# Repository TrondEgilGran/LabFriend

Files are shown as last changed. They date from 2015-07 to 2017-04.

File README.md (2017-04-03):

# LabFriend
Open Source USB Oscilloscope

Complete Open-Source USB basted oscillosope and measurement system.
2 Analog 200Msps channels 8 bit.
8 Digital 200Msps channels.
8 Digital Outputs
2 97KHz Audio frequency channel IO 24 bit.
3 High accuracy 16 bit DC inputs
1 8 bit 3Msps (low accuracy DAC).
1 DC output 0-5V max 20mA.

C-library for accessing HW. 
QT GUI Application.

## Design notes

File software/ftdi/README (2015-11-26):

To write SPI EEPROM on the ftdi chip using the programming tool from libftdi:
erase:
ftdi_eeprom --erase-eeprom  labfriend-usb.conf
flash:
ftdi_eeprom --flash-eeprom  labfriend-usb.conf

Make sure normal users have access to the FTDI device put the following
file:
53-teg-labfriend-usb.rules
to
/etc/udev/rules.d/
(this is for most modern Linux distributions in 2015 running udev)

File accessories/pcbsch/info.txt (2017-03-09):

pcb and shematics fro accesssories to then labfriend scope

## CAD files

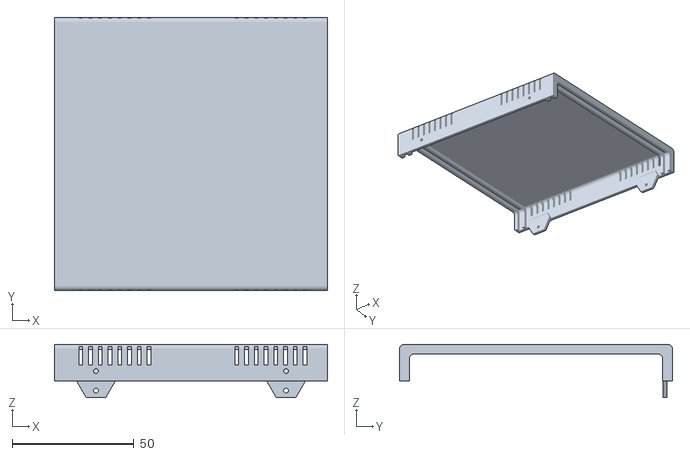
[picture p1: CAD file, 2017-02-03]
box/top.stl
112.0 x 112.0 x 21.9

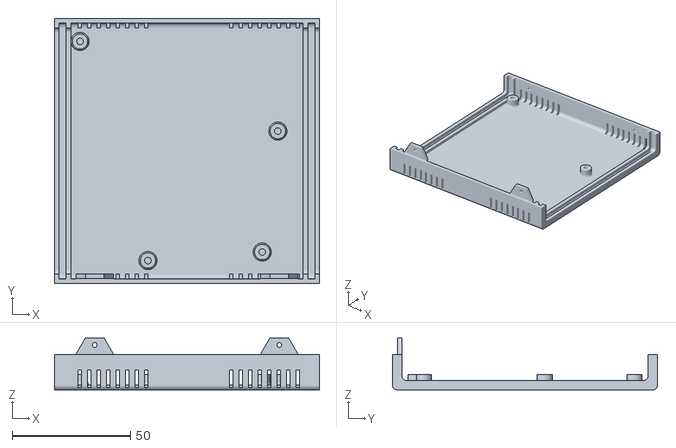
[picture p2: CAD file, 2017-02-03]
box/botom.stl
112.0 x 112.0 x 21.9

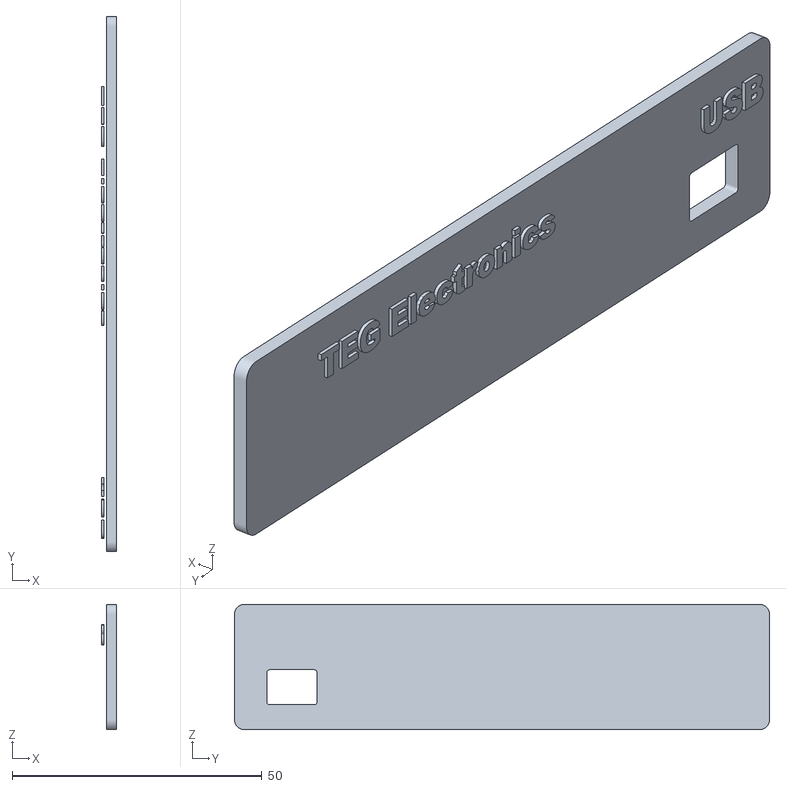
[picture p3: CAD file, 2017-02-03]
box/backpanel.stl
3.00 x 107.1 x 25.1

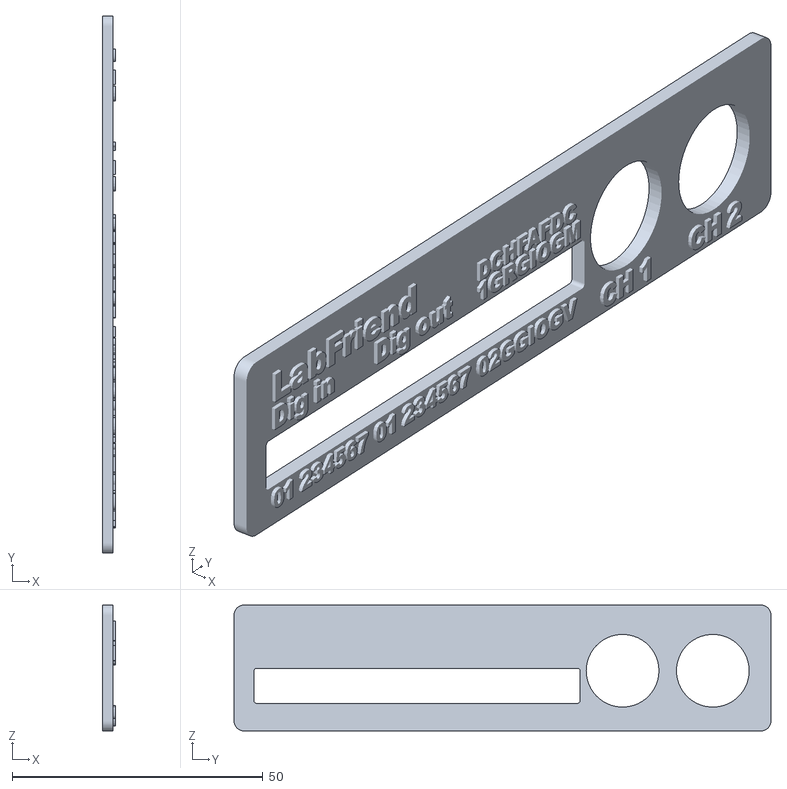
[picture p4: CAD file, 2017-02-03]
box/frontpanel.stl
2.50 x 107.1 x 25.1

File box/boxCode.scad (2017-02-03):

/*//////////////////////////////////////////////////////////////////
              -    FB Aka Heartman/Hearty 2016     -                   
              -   http://heartygfx.blogspot.com    -                  
              -       OpenScad Parametric Box      -                     
              -         CC BY-NC 3.0 License       -                      
////////////////////////////////////////////////////////////////////                                                                                                             
12/02/2016 - Fixed minor bug 
28/02/2016 - Added holes ventilation option                    
09/03/2016 - Added PCB feet support, fixed the shell artefact on export mode. 

*/////////////////////////// - Info - //////////////////////////////

// All coordinates are starting as integrated circuit pins.
// From the top view :

//   CoordD           <---       CoordC
//                                 ^
//                                 ^
//                                 ^
//   CoordA           --->       CoordB


////////////////////////////////////////////////////////////////////


////////// - Paramètres de la boite - Box parameters - /////////////

/* [Box dimensions] */
// - Longueur - Length  
  Length        = 112;       
// - Largeur - Width
  Width         = 112;                     
// - Hauteur - Height  
  Height        = 30;  
// - Epaisseur - Wall thickness  
  Thick         = 2;//[2:5]  
  
/* [Box options] */
// - Diamètre Coin arrondi - Filet diameter  
  Filet         = 2;//[0.1:12] 
// - lissage de l'arrondi - Filet smoothness  
  Resolution    = 50;//[1:100] 
// - Tolérance - Tolerance (Panel/rails gap)
  m             = 0.9;
// Pieds PCB - PCB feet (x4) 
  PCBFeet       = 0;// [0:No, 1:Yes]
// - Decorations to ventilation holes
  Vent          = 1;// [0:No, 1:Yes]
// - Decoration-Holes width (in mm)
  Vent_width    = 1.5;   


  
/* [PCB_Feet] */
//All dimensions are from the center foot axis

// - Coin bas gauche - Low left corner X position
PCBPosX         = 0;
// - Coin bas gauche - Low left corner Y position
PCBPosY         = 4;
// - Longueur PCB - PCB Length
PCBLength       = 100;
// - Largeur PCB - PCB Width
PCBWidth        = 100;
// - Heuteur pied - Feet height
FootHeight      = 7;
// - Diamètre pied - Foot diameter
FootDia         = 6.5;
// - Diamètre trou - Hole diameter
FootHole        = 2.8;  

Foot1PosX        = 33.5;
Foot1PosY        = 3.7;
Foot2PosX        = 4.8;
Foot2PosY        = 96.3;
Foot3PosX        = 88.4;
Foot3PosY        = 58.4;
Foot4PosX        = 81.8;
Foot4PosY        = 7.3;
  

/* [STL element to export] */
//Coque haut - Top shell
TShell          = 0;// [0:No, 1:Yes]
//Coque bas- Bottom shell
BShell          = 0;// [0:No, 1:Yes]
//Panneau avant - Front panel
FPanL           = 0;// [0:No, 1:Yes]
//Panneau arrière - Back panel  
BPanL           = 1;// [0:No, 1:Yes]


  
/* [Hidden] */
// - Couleur coque - Shell color  
Couleur1        = "Orange";       
// - Couleur panneaux - Panels color    
Couleur2        = "OrangeRed";    
// Thick X 2 - making decorations thicker if it is a vent to make sure they go through shell
Dec_Thick       = Vent ? Thick*2 : Thick; 
// - Depth decoration
Dec_size        = Vent ? Thick*2 : 0.8;





/////////// - Boitier générique bord arrondis - Generic rounded box - //////////

module RoundBox($a=Length, $b=Width, $c=Height){// Cube bords arrondis
                    $fn=Resolution;            
                    translate([0,Filet,Filet]){  
                    minkowski (){                                              
                        cube ([$a-(Length/2),$b-(2*Filet),$c-(2*Filet)], center = false);
                        rotate([0,90,0]){    
                        cylinder(r=Filet,h=Length/2, center = false);
                            } 
                        }
                    }
                }// End of RoundBox Module

      
////////////////////////////////// - Module Coque/Shell - //////////////////////////////////         

module Coque(){//Coque - Shell  
    Thick = Thick*2;  
    difference(){    
        difference(){//sides decoration
            union(){    
                     difference() {//soustraction de la forme centrale - Substraction Fileted box
                      
                        difference(){//soustraction cube median - Median cube slicer
                            union() {//union               
                            difference(){//Coque    
                                RoundBox();
                                translate([Thick/2,Thick/2,Thick/2]){     
                                        RoundBox($a=Length-Thick, $b=Width-Thick, $c=Height-Thick);
                                        }
                                        }//Fin diff Coque                            
                                difference(){//largeur Rails        
                                     translate([Thick+m,Thick/2,Thick/2]){// Rails
                                          RoundBox($a=Length-((2*Thick)+(2*m)), $b=Width-Thick, $c=Height-(Thick*2));
                                                          }//fin Rails
                                     translate([((Thick+m/2)*1.55),Thick/2,Thick/2+0.1]){ // +0.1 added to avoid the artefact
                                          RoundBox($a=Length-((Thick*3)+2*m), $b=Width-Thick, $c=Height-Thick);
                                                    }           
                                                }//Fin largeur Rails
                                    }//Fin union                                   
                               translate([-Thick,-Thick,Height/2]){// Cube à soustraire
                                    cube ([Length+100, Width+100, Height], center=false);
                                            }                                            
                                      }//fin soustraction cube median - End Median cube slicer
                               translate([-Thick/2,Thick,Thick]){// Forme de soustraction centrale 
                                    RoundBox($a=Length+Thick, $b=Width-Thick*2, $c=Height-Thick);       
                                    }                          
                                }                                          


                difference(){// wall fixation box legs
                    union(){
                        translate([3*Thick +5,Thick,Height/2]){
                            rotate([90,0,0]){
                                    $fn=6;
                                    cylinder(d=16,Thick/2);
                                    }   
                            }
                            
                       translate([Length-((3*Thick)+5),Thick,Height/2]){
                            rotate([90,0,0]){
                                    $fn=6;
                                    cylinder(d=16,Thick/2);
                                    }   
                            }

                        }
                            translate([4,Thick+Filet,Height/2-57]){   
                             rotate([45,0,0]){
                                   cube([Length,40,40]);    
                                  }
                           }
                           translate([0,-(Thick*1.46),Height/2]){
                                cube([Length,Thick*2,10]);
                           }
                    } //Fin fixation box legs
            }

        union(){// outbox sides decorations
            
            for(i=[0:Thick:Length/4]){

                // Ventilation holes part code submitted by Ettie - Thanks ;) 
                    translate([10+i,-Dec_Thick+Dec_size,1]){
                    cube([Vent_width,Dec_Thick,Height/4]);
                    }
                    translate([(Length-10) - i,-Dec_Thick+Dec_size,1]){
                    cube([Vent_width,Dec_Thick,Height/4]);
                    }
                    translate([(Length-10) - i,Width-Dec_size,1]){
                    cube([Vent_width,Dec_Thick,Height/4]);
                    }
                    translate([10+i,Width-Dec_size,1]){
                    cube([Vent_width,Dec_Thick,Height/4]);
                    }
  
                
                    }// fin de for
               // }
                }//fin union decoration
            }//fin difference decoration
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

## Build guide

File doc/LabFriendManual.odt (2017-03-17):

LabFriend Manual

# Connectors

Hhh

'

Pin Number | Function
1 | CMPMEAS, Component measurement pin (caps inductors, resistors)
2 | EXVO, Voltage output, max 50mA 5V (adjustable)
3 | GND
4 | GND
5 | AOUTR, High Resolution AF channel 1 output
6 | AOUTL, High Resolution AF channel 2 output
7 | AINR, High Resolution AF channel 1 input
8 | AINL, High Resolution AF channel 2 input
9 | GND
10 | GND
11 | HFDAC, 3MHz DAC out, 8 bit 0 - 5V
12 | GND
13 | GND
14 | DCMEAS3, DC measurement 0-5V 16bit +gain
15 | DCMEAS1, DC measurement 0-5V 16bit +gain (can be used with channel 2 in diff m)
15 | DCMEAS2, DC measurement 0-5V 16bit +gain

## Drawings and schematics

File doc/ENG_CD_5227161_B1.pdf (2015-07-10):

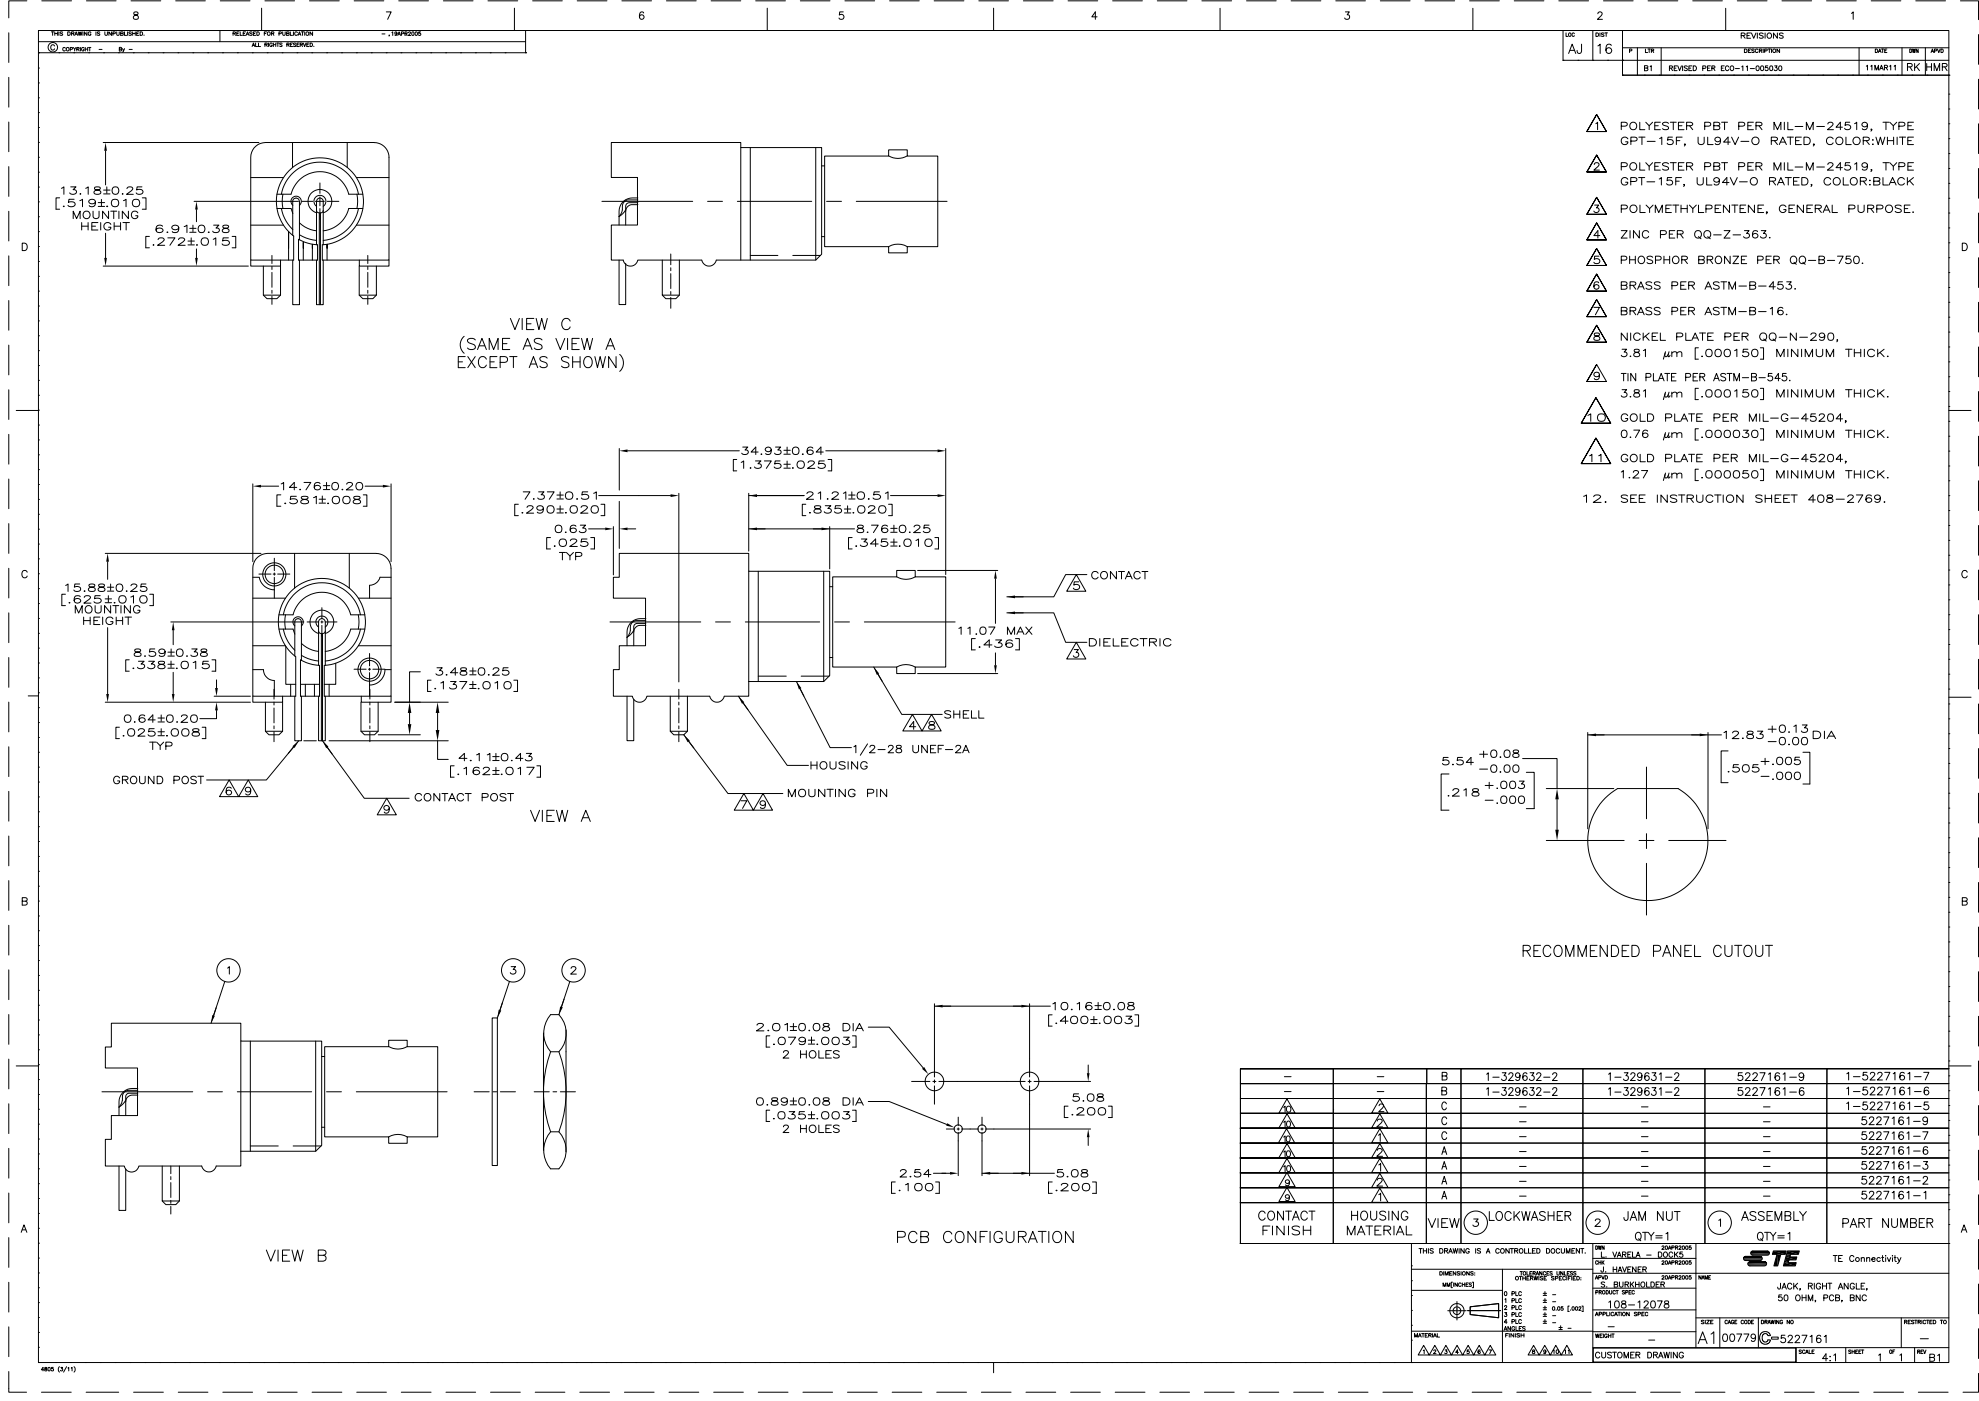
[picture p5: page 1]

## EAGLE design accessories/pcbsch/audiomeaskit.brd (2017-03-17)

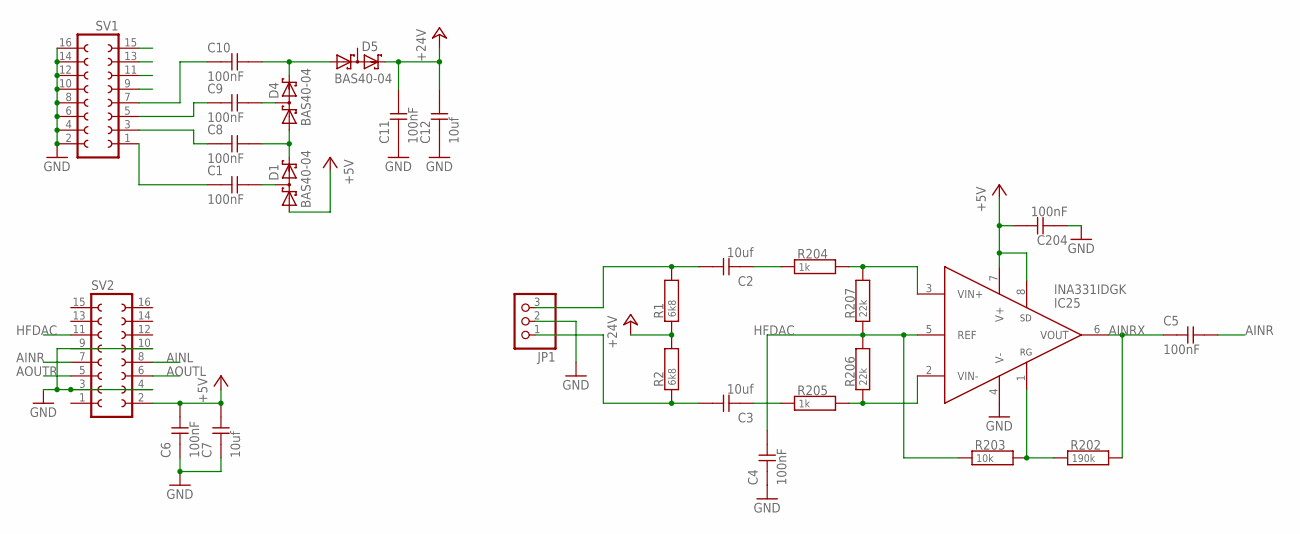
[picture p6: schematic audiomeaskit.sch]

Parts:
C1, C4, C5, C6, C8, C9, C10, C11: 100nF; 0603
C2, C3, C7, C12: 10uf; 0805
C204: 100nF; 0402
D1, D4, D5: BAS40-04; SOT23
IC25: INA331IDGK; MSOP08
JP1: PINHD-1X3; 1X03
R1, R2: 6k8; 0603
R202: 190k; 0603
R203: 10k; 0603
R204, R205: 1k; 0603
R206, R207: 22k; 0603
SV1, SV2: FE08-2

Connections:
+5V: C6.2, C7.2, C204.2, D1.1 (A1), IC25.7 (V+), IC25.8 (SD), SV2.2
+24V: C11.2, C12.2, D5.2 (C2), R1.1, R2.2
AINL: SV2.8
AINR: C5.2, SV2.7
AINRX: C5.1, IC25.6 (VOUT), R202.2
AOUTL: SV2.6
AOUTR: SV2.5
GND: C4.1, C6.1, C7.1, C11.1, C12.1, C204.1, IC25.4 (V-), JP1.2, SV1.2, SV1.4, SV1.6, SV1.8, SV1.10, SV1.12, SV1.14, SV1.16, SV2.3, SV2.4, SV2.9, SV2.10
HFDAC: C4.2, IC25.5 (REF), R203.1, R206.2, R207.1, SV2.11
unnamed: C8.1, SV1.3
unnamed: C3.2, JP1.1, R2.1
unnamed: C2.2, JP1.3, R1.2
unnamed: C1.1, SV1.1
unnamed: C1.2, D1.3 (C1A2)
unnamed: C10.1, SV1.7
unnamed: C8.2, D1.2 (C2), D4.1 (A1)
unnamed: C9.1, SV1.5
unnamed: C9.2, D4.3 (C1A2)
unnamed: C10.2, D4.2 (C2), D5.1 (A1)
unnamed: IC25.1 (RG), R202.1, R203.2
unnamed: IC25.3 (VIN+), R204.2, R207.2
unnamed: IC25.2 (VIN-), R205.2, R206.1
unnamed: C2.1, R204.1
unnamed: C3.1, R205.1
S1: SV1.9
S2: SV1.11
S3: SV1.13
S4: SV1.15

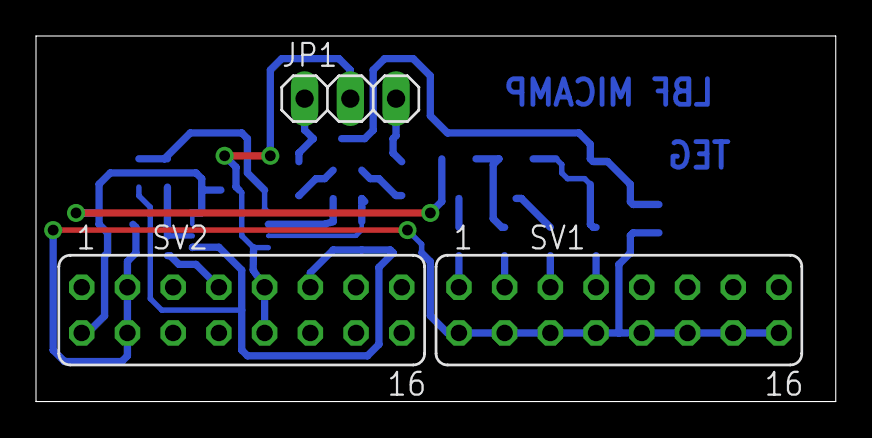
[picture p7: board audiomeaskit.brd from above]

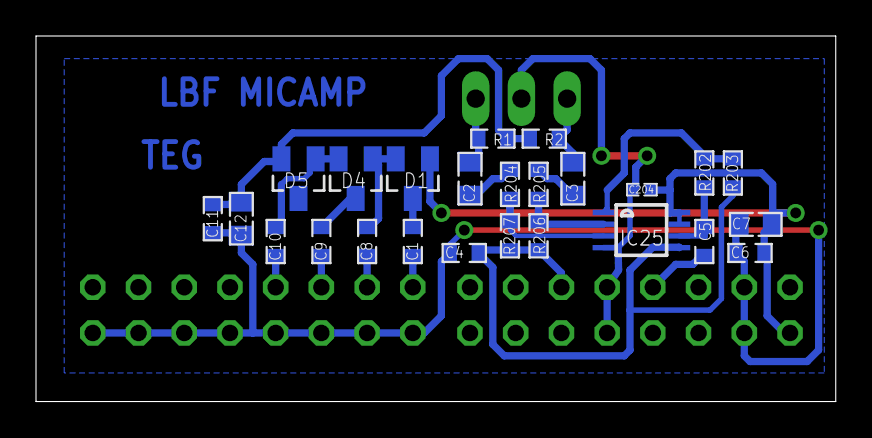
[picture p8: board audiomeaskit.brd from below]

Board: 2 copper layers, 44.4 x 20.3 mm, 28 parts (25 on the bottom side), 21 nets.

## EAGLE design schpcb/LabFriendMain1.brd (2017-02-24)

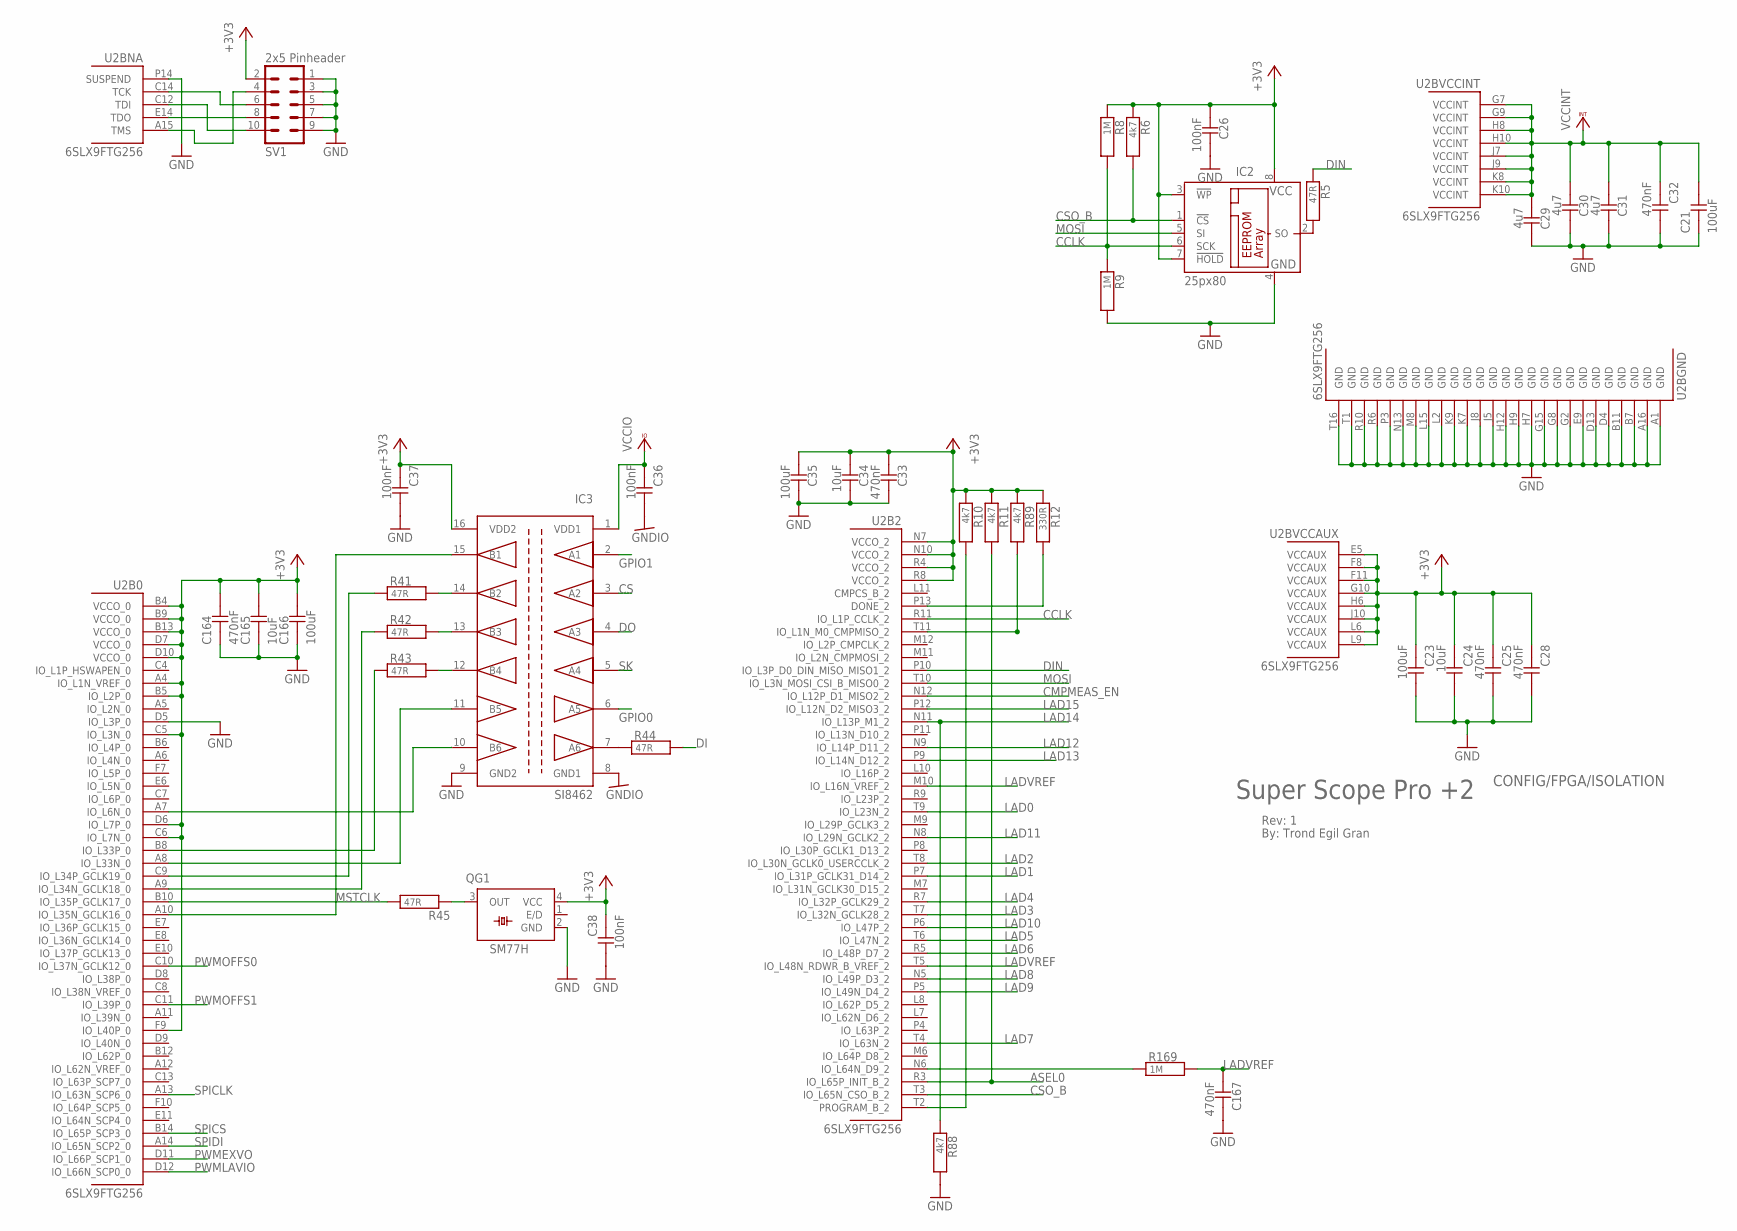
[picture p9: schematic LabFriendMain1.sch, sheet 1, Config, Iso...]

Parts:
C21, C23, C35, C166: 100uF; 1206
C24, C34, C165: 10uF; 0603
C25, C28, C32, C33, C164, C167: 470nF; 0402
C26, C36, C37, C38: 100nF; 0402
C29, C30, C31: 4u7; 0603
IC2: 25px80; SO-08
IC3: SI8462; SO16
QG1: SM77H
R5, R41, R42, R43, R44, R45: 47R; 0402
R6, R10, R11, R88, R89: 4k7; 0402
R8, R9, R169: 1M; 0402
R12: 330R; 0402
SV1: 2x5 Pinheader; ML10
U2: 6SLX9FTG256; FT256

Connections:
+3V3: C23.1, C24.1, C25.1, C26.1, C28.1, C33.1, C34.1, C35.1, C37.1, C38.1, C164.2, C165.2, C166.2, IC2.3 (!WP), IC2.7 (!HOLD), IC2.8 (VCC), IC3.16 (VDD2), QG1.4 (VCC), R6.1, R8.1, R10.1, R11.1, R12.1, R89.1, SV1.2, U2.A4 (IO_L1N_VREF_0), U2.B4 (VCCO_0), U2.B5 (IO_L2P_0), U2.B9 (VCCO_0), U2.B13 (VCCO_0), U2.C5 (IO_L3N_0), U2.C6 (IO_L7N_0), U2.D6 (IO_L7P_0), U2.D7 (VCCO_0), U2.D10 (VCCO_0), U2.E5 (VCCAUX), U2.F8 (VCCAUX), U2.F9 (IO_L40P_0), U2.F11 (VCCAUX), U2.G10 (VCCAUX), U2.H6 (VCCAUX), U2.J10 (VCCAUX), U2.L6 (VCCAUX), U2.L9 (VCCAUX), U2.N7 (VCCO_2), U2.N10 (VCCO_2), U2.R4 (VCCO_2), U2.R8 (VCCO_2); also elsewhere on the board
ASEL0: R11.2, U2.R3 (IO_L65P_INIT_B_2)
CCLK: IC2.6 (SCK), R8.2, R9.1, U2.R11 (IO_L1P_CCLK_2)
CMPMEAS_EN: U2.N12 (IO_L12P_D1_MISO2_2); also elsewhere on the board
CS: IC3.3 (A2); also elsewhere on the board
CSO_B: IC2.1 (!CS), R6.2, U2.T3 (IO_L65N_CSO_B_2)
DI: R44.2; also elsewhere on the board
DIN: R5.1, U2.P10 (IO_L3P_D0_DIN_MISO_MISO1_2)
DO: IC3.4 (A3); also elsewhere on the board
GND: C21.1, C23.2, C24.2, C25.2, C26.2, C28.2, C29.2, C30.2, C31.2, C32.2, C33.2, C34.2, C35.2, C37.2, C38.2, C164.1, C165.1, C166.1, C167.2, IC2.4 (GND), IC3.9 (GND2), QG1.2 (GND), R9.2, R88.2, SV1.1, SV1.3, SV1.5, SV1.7, SV1.9, U2.A1 (GND), U2.A16 (GND), U2.B7 (GND), U2.B11 (GND), U2.D4 (GND), U2.D5 (IO_L3P_0), U2.D13 (GND), U2.E9 (GND), U2.G2 (GND), U2.G8 (GND), U2.G15 (GND), U2.H7 (GND), U2.H9 (GND), U2.H12 (GND), U2.J5 (GND), U2.J8 (GND), U2.K7 (GND), U2.K9 (GND), U2.L2 (GND), U2.L15 (GND), U2.M8 (GND), U2.N13 (GND), U2.P3 (GND), U2.P14 (SUSPEND), U2.R6 (GND), U2.R10 (GND), U2.T1 (GND), U2.T16 (GND); also elsewhere on the board
GNDIO: C36.2, IC3.8 (GND1); also elsewhere on the board
GPIO0: IC3.6 (A5); also elsewhere on the board
GPIO1: IC3.2 (A1); also elsewhere on the board
LAD0: U2.T9 (IO_L23N_2); also elsewhere on the board
LAD1: U2.P7 (IO_L31P_GCLK31_D14_2); also elsewhere on the board
LAD2: U2.T8 (IO_L30N_GCLK0_USERCCLK_2); also elsewhere on the board
LAD3: U2.T7 (IO_L32N_GCLK28_2); also elsewhere on the board
LAD4: U2.R7 (IO_L32P_GCLK29_2); also elsewhere on the board
LAD5: U2.T6 (IO_L47N_2); also elsewhere on the board
LAD6: U2.R5 (IO_L48P_D7_2); also elsewhere on the board
LAD7: U2.T4 (IO_L63N_2); also elsewhere on the board
LAD8: U2.N5 (IO_L49P_D3_2); also elsewhere on the board
LAD9: U2.P5 (IO_L49N_D4_2); also elsewhere on the board
LAD10: U2.P6 (IO_L47P_2); also elsewhere on the board
LAD11: U2.N8 (IO_L29N_GCLK2_2); also elsewhere on the board
LAD12: U2.N9 (IO_L14P_D11_2); also elsewhere on the board
LAD13: U2.P9 (IO_L14N_D12_2); also elsewhere on the board
LAD14: R88.1, U2.N11 (IO_L13P_M1_2); also elsewhere on the board
LAD15: U2.P12 (IO_L12N_D2_MISO3_2); also elsewhere on the board
LADVREF: C167.1, R169.2, U2.M10 (IO_L16N_VREF_2), U2.T5 (IO_L48N_RDWR_B_VREF_2)
MOSI: IC2.5 (SI), U2.T10 (IO_L3N_MOSI_CSI_B_MISO0_2)
MSTCLK: R45.1, U2.B10 (IO_L35P_GCLK17_0)
unnamed: IC3.14 (B2), R41.2
unnamed: IC2.2 (SO), R5.2
unnamed: R10.2, U2.T2 (PROGRAM_B_2)
unnamed: R12.2, U2.P13 (DONE_2)
unnamed: IC3.15 (B1), U2.A10 (IO_L35N_GCLK16_0)
unnamed: SV1.4, U2.A15 (TMS)
unnamed: SV1.6, U2.C14 (TCK)
unnamed: SV1.8, U2.E14 (TDO)
unnamed: SV1.10, U2.C12 (TDI)
unnamed: R41.1, U2.C9 (IO_L34P_GCLK19_0)
unnamed: R42.1, U2.A9 (IO_L34N_GCLK18_0)
unnamed: IC3.10 (B6), U2.A7 (IO_L6N_0)
unnamed: IC3.13 (B3), R42.2
unnamed: IC3.12 (B4), R43.2
unnamed: IC3.7 (A6), R44.1
unnamed: QG1.3 (OUT), R45.2
unnamed: IC3.11 (B5), U2.A8 (IO_L33N_0)
unnamed: R43.1, U2.B8 (IO_L33P_0)
unnamed: R169.1, U2.N6 (IO_L64N_D9_2)
PULLUP1XA: R89.2, U2.T11 (IO_L1N_M0_CMPMISO_2)
PWMEXVO: U2.D11 (IO_L66P_SCP1_0); also elsewhere on the board
PWMLAVIO: U2.D12 (IO_L66N_SCP0_0); also elsewhere on the board
PWMOFFS0: U2.C10 (IO_L37N_GCLK12_0); also elsewhere on the board
PWMOFFS1: U2.C11 (IO_L39P_0); also elsewhere on the board
SK: IC3.5 (A4); also elsewhere on the board
SPICLK: U2.A13 (IO_L63N_SCP6_0); also elsewhere on the board
SPICS: U2.B14 (IO_L65P_SCP3_0); also elsewhere on the board
SPIDI: U2.A14 (IO_L65N_SCP2_0); also elsewhere on the board
VCCINT: C21.2, C29.1, C30.1, C31.1, C32.1, U2.G7 (VCCINT), U2.G9 (VCCINT), U2.H8 (VCCINT), U2.H10 (VCCINT), U2.J7 (VCCINT), U2.J9 (VCCINT), U2.K8 (VCCINT), U2.K10 (VCCINT); also elsewhere on the board
VCCIO: C36.1, IC3.1 (VDD1); also elsewhere on the board

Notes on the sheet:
Rev: 1
By: Trond Egil Gran
Super Scope Pro +2
CONFIG/FPGA/ISOLATION

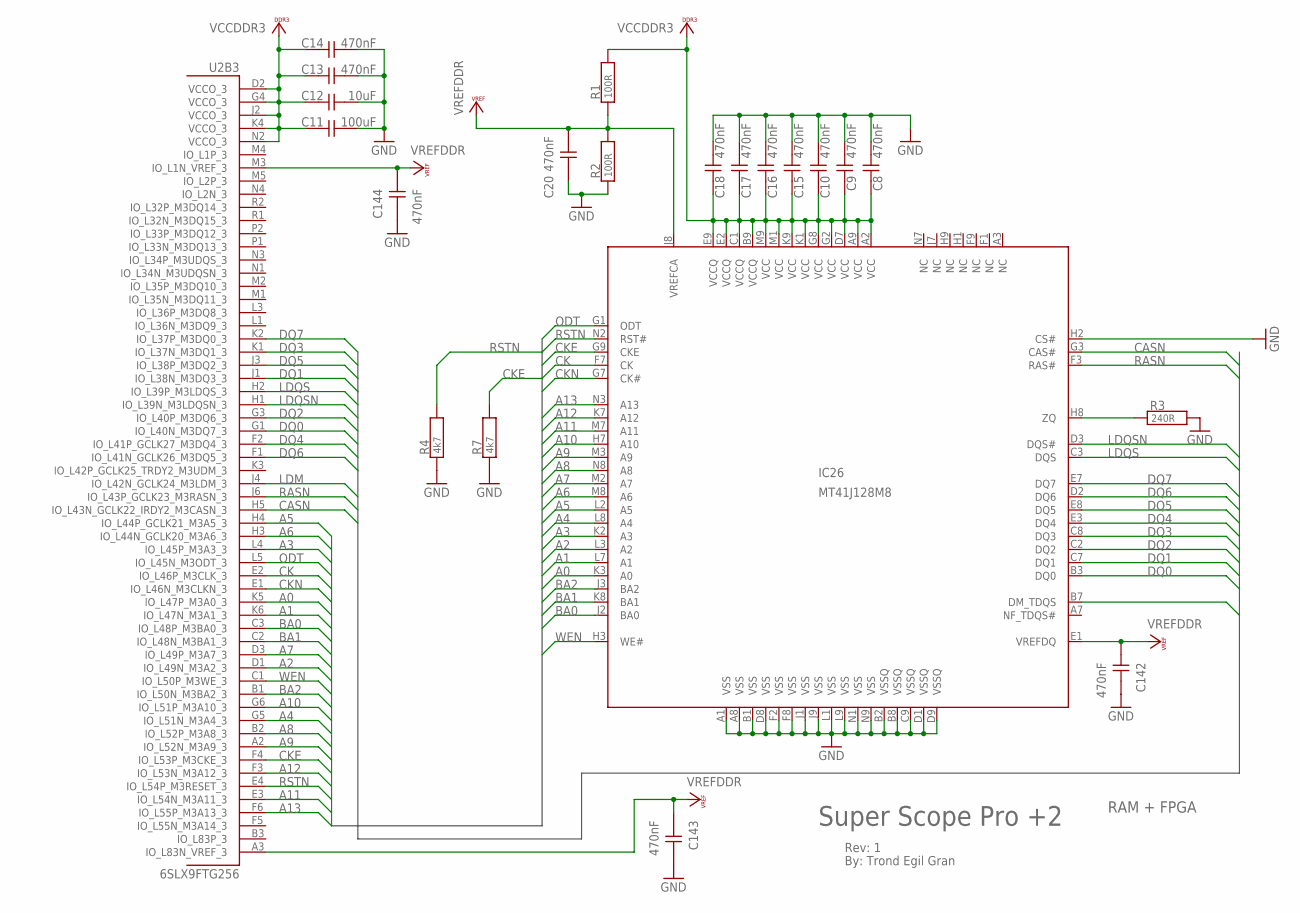
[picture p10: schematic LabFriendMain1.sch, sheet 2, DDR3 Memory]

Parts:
C8, C9, C10, C13, C14, C15, C16, C17, C18, C20, C142, C143, C144: 470nF; 0402
C11: 100uF; 1206
C12: 10uF; 0603
IC26: MT41J128M8; FBGA78
R1, R2: 100R; 0402
R3: 240R; 0603
R4, R7: 4k7; 0402
U2: 6SLX9FTG256; FT256

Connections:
A0: IC26.K3 (A0), U2.K5 (IO_L47P_M3A0_3)
A1: IC26.L7 (A1), U2.K6 (IO_L47N_M3A1_3)
A2: IC26.L3 (A2), U2.D1 (IO_L49N_M3A2_3)
A3: IC26.K2 (A3), U2.L4 (IO_L45P_M3A3_3)
A4: IC26.L8 (A4), U2.G5 (IO_L51N_M3A4_3)
A5: IC26.L2 (A5), U2.H4 (IO_L44P_GCLK21_M3A5_3)
A6: IC26.M8 (A6), U2.H3 (IO_L44N_GCLK20_M3A6_3)
A7: IC26.M2 (A7), U2.D3 (IO_L49P_M3A7_3)
A8: IC26.N8 (A8), U2.B2 (IO_L52P_M3A8_3)
A9: IC26.M3 (A9), U2.A2 (IO_L52N_M3A9_3)
A10: IC26.H7 (A10), U2.G6 (IO_L51P_M3A10_3)
A11: IC26.M7 (A11), U2.E3 (IO_L54N_M3A11_3)
A12: IC26.K7 (A12), U2.F3 (IO_L53N_M3A12_3)
A13: IC26.N3 (A13), U2.F6 (IO_L55P_M3A13_3)
BA0: IC26.J2 (BA0), U2.C3 (IO_L48P_M3BA0_3)
BA1: IC26.K8 (BA1), U2.C2 (IO_L48N_M3BA1_3)
BA2: IC26.J3 (BA2), U2.B1 (IO_L50N_M3BA2_3)
CASN: IC26.G3 (CAS#), U2.H5 (IO_L43N_GCLK22_IRDY2_M3CASN_3)
CK: IC26.F7 (CK), U2.E2 (IO_L46P_M3CLK_3)
CKE: IC26.G9 (CKE), R7.2, U2.F4 (IO_L53P_M3CKE_3)
CKN: IC26.G7 (CK#), U2.E1 (IO_L46N_M3CLKN_3)
DQ0: IC26.B3 (DQ0), U2.G1 (IO_L40N_M3DQ7_3)
DQ1: IC26.C7 (DQ1), U2.J1 (IO_L38N_M3DQ3_3)
DQ2: IC26.C2 (DQ2), U2.G3 (IO_L40P_M3DQ6_3)
DQ3: IC26.C8 (DQ3), U2.K1 (IO_L37N_M3DQ1_3)
DQ4: IC26.E3 (DQ4), U2.F2 (IO_L41P_GCLK27_M3DQ4_3)
DQ5: IC26.E8 (DQ5), U2.J3 (IO_L38P_M3DQ2_3)
DQ6: IC26.D2 (DQ6), U2.F1 (IO_L41N_GCLK26_M3DQ5_3)
DQ7: IC26.E7 (DQ7), U2.K2 (IO_L37P_M3DQ0_3)
GND: C8.2, C9.2, C10.2, C11.2, C12.2, C13.2, C14.2, C15.2, C16.2, C17.2, C18.2, C20.1, C142.1, C143.1, C144.1, IC26.A1 (VSS), IC26.A8 (VSS), IC26.B1 (VSS), IC26.B2 (VSSQ), IC26.B8 (VSSQ), IC26.C9 (VSSQ), IC26.D1 (VSSQ), IC26.D8 (VSS), IC26.D9 (VSSQ), IC26.F2 (VSS), IC26.F8 (VSS), IC26.H2 (CS#), IC26.J1 (VSS), IC26.J9 (VSS), IC26.L1 (VSS), IC26.L9 (VSS), IC26.N1 (VSS), IC26.N9 (VSS), R2.1, R3.2, R4.1, R7.1; also elsewhere on the board
LDM: IC26.B7 (DM_TDQS), U2.J4 (IO_L42N_GCLK24_M3LDM_3)
LDQS: IC26.C3 (DQS), U2.H2 (IO_L39P_M3LDQS_3)
LDQSN: IC26.D3 (DQS#), U2.H1 (IO_L39N_M3LDQSN_3)
unnamed: IC26.H8 (ZQ), R3.1
ODT: IC26.G1 (ODT), U2.L5 (IO_L45N_M3ODT_3)
RASN: IC26.F3 (RAS#), U2.J6 (IO_L43P_GCLK23_M3RASN_3)
RSTN: IC26.N2 (RST#), R4.2, U2.E4 (IO_L54P_M3RESET_3)
VCCDDR3: C8.1, C9.1, C10.1, C11.1, C12.1, C13.1, C14.1, C15.1, C16.1, C17.1, C18.1, IC26.A2 (VCC), IC26.A9 (VCC), IC26.B9 (VCCQ), IC26.C1 (VCCQ), IC26.D7 (VCC), IC26.E2 (VCCQ), IC26.E9 (VCCQ), IC26.G2 (VCC), IC26.G8 (VCC), IC26.K1 (VCC), IC26.K9 (VCC), IC26.M1 (VCC), IC26.M9 (VCC), R1.2, U2.D2 (VCCO_3), U2.G4 (VCCO_3), U2.J2 (VCCO_3), U2.K4 (VCCO_3), U2.N2 (VCCO_3); also elsewhere on the board
VREFDDR: C20.2, C142.2, C143.2, C144.2, IC26.E1 (VREFDQ), IC26.J8 (VREFCA), R1.1, R2.2, U2.A3 (IO_L83N_VREF_3), U2.M3 (IO_L1N_VREF_3)
WEN: IC26.H3 (WE#), U2.C1 (IO_L50P_M3WE_3)

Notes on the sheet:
Rev: 1
By: Trond Egil Gran
Super Scope Pro +2
RAM + FPGA

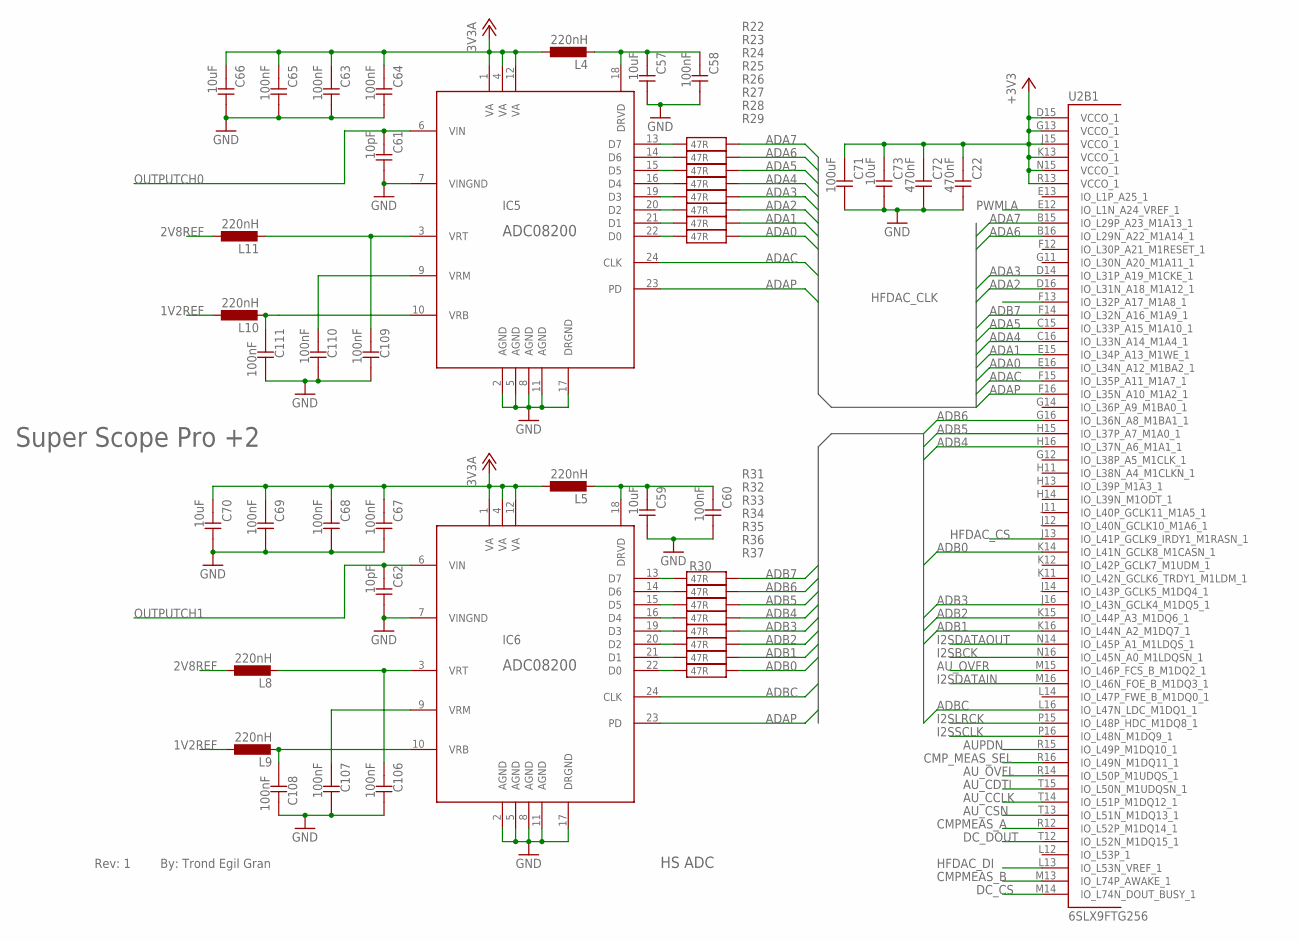
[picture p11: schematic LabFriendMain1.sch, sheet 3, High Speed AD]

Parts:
C22, C72: 470nF; 0402
C57, C59, C66, C70, C73: 10uF; 0603
C58, C60, C63, C64, C65, C67, C68, C69, C106, C107, C108, C109, C110, C111: 100nF; 0402
C61, C62: 10pF; 0402
C71: 100uF; 1206
IC5, IC6: ADC08200; TSSOP24
L4, L5, L8, L9, L10, L11: 220nH; 0603
R22, R23, R24, R25, R26, R27, R28, R29, R30, R31, R32, R33, R34, R35, R36, R37: 47R; 0402
U2: 6SLX9FTG256; FT256

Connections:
1V2REF: L9.1, L10.1; also elsewhere on the board
1V2REFAD0: C111.1, IC5.10 (VRB), L10.2
1V2REFAD1: C108.1, IC6.10 (VRB), L9.2
2V8REF: L8.1, L11.1; also elsewhere on the board
2V8REFAD0: C109.1, IC5.3 (VRT), L11.2
2V8REFAD1: C106.1, IC6.3 (VRT), L8.2
3V3A: C63.1, C64.1, C65.1, C66.1, C67.1, C68.1, C69.1, C70.1, IC5.1 (VA), IC5.4 (VA), IC5.12 (VA), IC6.1 (VA), IC6.4 (VA), IC6.12 (VA), L4.1, L5.1; also elsewhere on the board
+3V3: C22.1, C71.1, C72.1, C73.1, U2.D15 (VCCO_1), U2.G13 (VCCO_1), U2.J15 (VCCO_1), U2.K13 (VCCO_1), U2.N15 (VCCO_1), U2.R13 (VCCO_1); also elsewhere on the board
ADA0: R29.2, U2.E16 (IO_L34N_A12_M1BA2_1)
ADA1: R28.2, U2.E15 (IO_L34P_A13_M1WE_1)
ADA2: R27.2, U2.D16 (IO_L31N_A18_M1A12_1)
ADA3: R26.2, U2.D14 (IO_L31P_A19_M1CKE_1)
ADA4: R25.2, U2.C16 (IO_L33N_A14_M1A4_1)
ADA5: R24.2, U2.C15 (IO_L33P_A15_M1A10_1)
ADA6: R23.2, U2.B16 (IO_L29N_A22_M1A14_1)
ADA7: R22.2, U2.B15 (IO_L29P_A23_M1A13_1)
ADAC: IC5.24 (CLK), U2.F15 (IO_L35P_A11_M1A7_1)
ADAP: IC5.23 (PD), IC6.23 (PD), U2.F16 (IO_L35N_A10_M1A2_1)
ADB0: R37.2, U2.K14 (IO_L41N_GCLK8_M1CASN_1)
ADB1: R36.2, U2.K16 (IO_L44N_A2_M1DQ7_1)
ADB2: R35.2, U2.K15 (IO_L44P_A3_M1DQ6_1)
ADB3: R34.2, U2.J16 (IO_L43N_GCLK4_M1DQ5_1)
ADB4: R33.2, U2.H16 (IO_L37N_A6_M1A1_1)
ADB5: R32.2, U2.H15 (IO_L37P_A7_M1A0_1)
ADB6: R31.2, U2.G16 (IO_L36N_A8_M1BA1_1)
ADB7: R30.2, U2.F14 (IO_L32N_A16_M1A9_1)
ADBC: IC6.24 (CLK), U2.L16 (IO_L47N_LDC_M1DQ1_1)
AUPDN: U2.R15 (IO_L49P_M1DQ10_1); also elsewhere on the board
AU_CCLK: U2.T14 (IO_L51P_M1DQ12_1); also elsewhere on the board
AU_CDTI: U2.T15 (IO_L50N_M1UDQSN_1); also elsewhere on the board
AU_CSN: U2.T13 (IO_L51N_M1DQ13_1); also elsewhere on the board
AU_OVFL: U2.R14 (IO_L50P_M1UDQS_1); also elsewhere on the board
AU_OVFR: U2.M15 (IO_L46P_FCS_B_M1DQ2_1); also elsewhere on the board
CMPMEAS_A: U2.R12 (IO_L52P_M1DQ14_1); also elsewhere on the board
CMPMEAS_B: U2.M13 (IO_L74P_AWAKE_1); also elsewhere on the board
CMP_MEAS_SEL: U2.R16 (IO_L49N_M1DQ11_1); also elsewhere on the board
DC_CS: U2.M14 (IO_L74N_DOUT_BUSY_1); also elsewhere on the board
DC_DOUT: U2.T12 (IO_L52N_M1DQ15_1); also elsewhere on the board
GND: C22.2, C57.2, C58.2, C59.2, C60.2, C61.2, C62.2, C63.2, C64.2, C65.2, C66.2, C67.2, C68.2, C69.2, C70.2, C71.2, C72.2, C73.2, C106.2, C107.2, C108.2, C109.2, C110.2, C111.2, IC5.2 (AGND), IC5.5 (AGND), IC5.7 (VINGND), IC5.8 (AGND), IC5.11 (AGND), IC5.17 (DRGND), IC6.2 (AGND), IC6.5 (AGND), IC6.7 (VINGND), IC6.8 (AGND), IC6.11 (AGND), IC6.17 (DRGND); also elsewhere on the board
HFDAC_CLK: U2.F13 (IO_L32P_A17_M1A8_1); also elsewhere on the board
HFDAC_CS: U2.J13 (IO_L41P_GCLK9_IRDY1_M1RASN_1); also elsewhere on the board
HFDAC_DI: U2.L13 (IO_L53N_VREF_1); also elsewhere on the board
I2SBCK: U2.N16 (IO_L45N_A0_M1LDQSN_1); also elsewhere on the board
I2SDATAIN: U2.M16 (IO_L46N_FOE_B_M1DQ3_1); also elsewhere on the board
I2SDATAOUT: U2.N14 (IO_L45P_A1_M1LDQS_1); also elsewhere on the board
I2SLRCK: U2.P15 (IO_L48P_HDC_M1DQ8_1); also elsewhere on the board
I2SSCLK: U2.P16 (IO_L48N_M1DQ9_1); also elsewhere on the board
unnamed: C57.1, C58.1, IC5.18 (DRVD), L4.2
unnamed: IC5.13 (D7), R22.1
unnamed: C59.1, C60.1, IC6.18 (DRVD), L5.2
unnamed: IC5.14 (D6), R23.1
unnamed: IC5.15 (D5), R24.1
unnamed: IC5.16 (D4), R25.1
unnamed: IC5.19 (D3), R26.1
unnamed: IC5.20 (D2), R27.1
unnamed: IC5.21 (D1), R28.1
unnamed: IC5.22 (D0), R29.1
unnamed: IC6.13 (D7), R30.1
unnamed: IC6.14 (D6), R31.1
unnamed: IC6.15 (D5), R32.1
unnamed: IC6.16 (D4), R33.1
unnamed: IC6.19 (D3), R34.1
unnamed: IC6.20 (D2), R35.1
unnamed: IC6.21 (D1), R36.1
unnamed: IC6.22 (D0), R37.1
NONO1: C110.1, IC5.9 (VRM)
NONO2: C107.1, IC6.9 (VRM)
OUTPUTCH0: C61.1, IC5.6 (VIN); also elsewhere on the board
OUTPUTCH1: C62.1, IC6.6 (VIN); also elsewhere on the board
PWMLA: U2.E12 (IO_L1N_A24_VREF_1); also elsewhere on the board

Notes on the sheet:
Rev: 1
By: Trond Egil Gran
Super Scope Pro +2
HS ADC

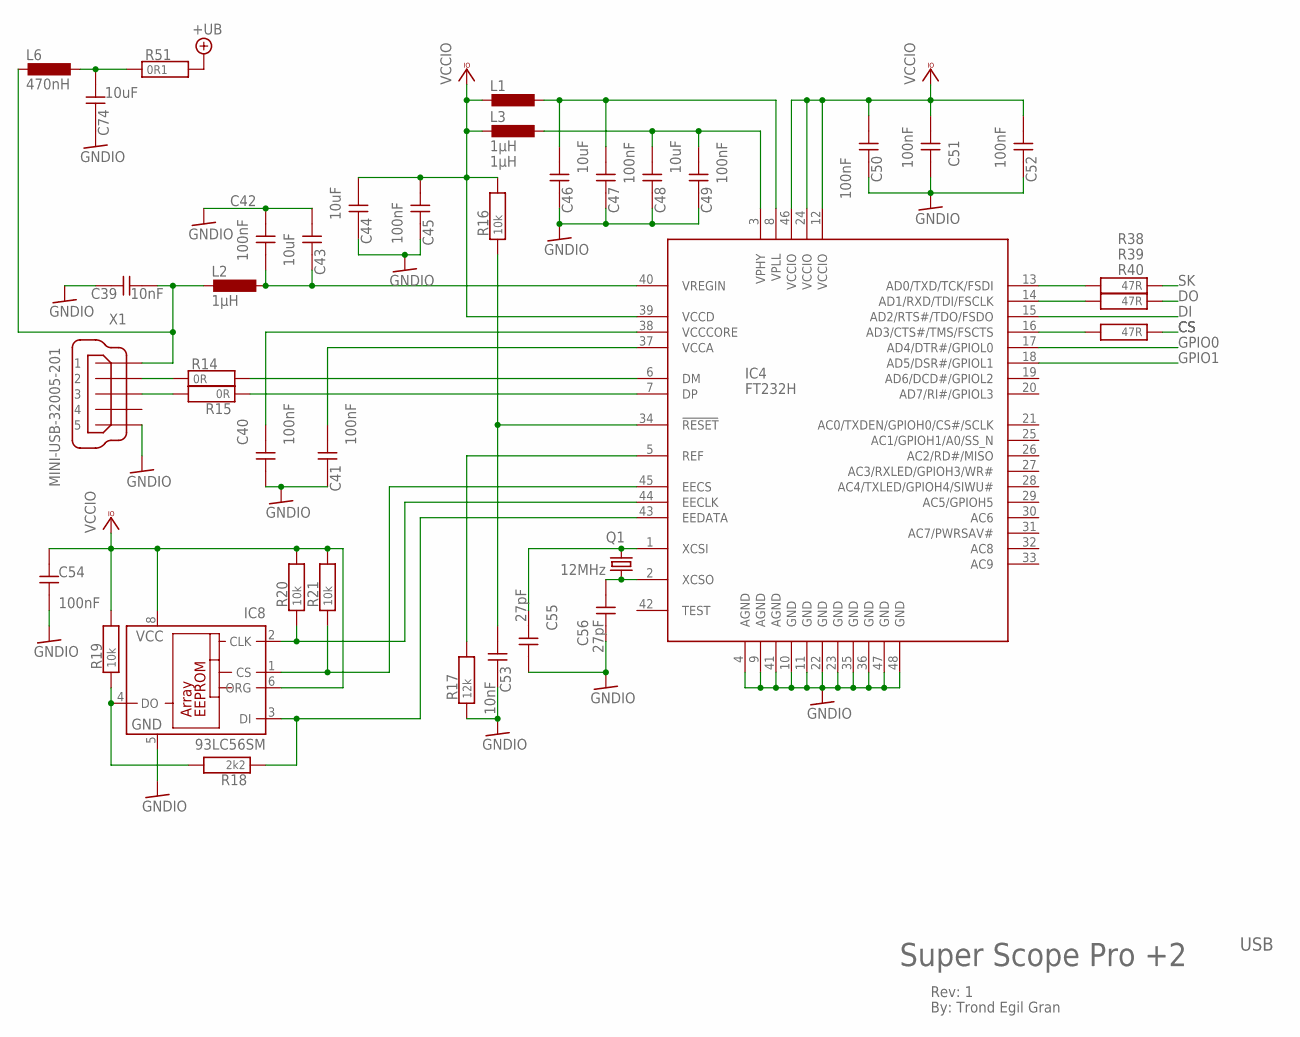
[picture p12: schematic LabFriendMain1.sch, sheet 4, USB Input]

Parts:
C39, C53: 10nF; 0402
C40, C41, C42, C45, C47, C49, C50, C51, C52, C54: 100nF; 0402
C43, C44, C46, C48, C74: 10uF; 0603
C55, C56: 27pF; 0603
IC4: FT232H; LQFP48
IC8: 93LC56SM; SO-08M
L1, L2, L3: 1µH; L3216C
L6: 470nH; L3216C
Q1: 12MHz; HC49UP
R14, R15: 0R; 0603
R16, R19, R20, R21: 10k; 0603
R17: 12k; 0603
R18: 2k2; 0402
R38, R39, R40: 47R; 0402
R51: 0R1; 0603
X1: MINI-USB-32005-201; 32005-201

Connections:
+UB: R51.2; also elsewhere on the board
CS: R40.1; also elsewhere on the board
DI: IC4.15 (AD2/RTS#/TDO/FSDO); also elsewhere on the board
DO: R39.1; also elsewhere on the board
GNDIO: C39.2, C40.2, C41.2, C42.1, C43.1, C44.2, C45.2, C46.2, C47.2, C48.2, C49.2, C50.2, C51.2, C52.2, C53.2, C54.2, C55.1, C56.1, C74.2, IC4.4 (AGND), IC4.9 (AGND), IC4.10 (GND), IC4.11 (GND), IC4.22 (GND), IC4.23 (GND), IC4.35 (GND), IC4.36 (GND), IC4.41 (AGND), IC4.47 (GND), IC4.48 (GND), IC8.5 (GND), R17.1, X1.5; also elsewhere on the board
GPIO0: IC4.17 (AD4/DTR#/GPIOL0); also elsewhere on the board
GPIO1: IC4.18 (AD5/DSR#/GPIOL1); also elsewhere on the board
unnamed: IC4.13 (AD0/TXD/TCK/FSDI), R38.2
unnamed: R14.1, X1.2
unnamed: C39.1, L2.2, L6.2, X1.1
unnamed: C42.2, C43.2, IC4.40 (VREGIN), L2.1
unnamed: IC4.6 (DM), R14.2
unnamed: IC4.7 (DP), R15.1
unnamed: R15.2, X1.3
unnamed: C41.1, IC4.37 (VCCA)
unnamed: C40.1, IC4.38 (VCCCORE)
unnamed: C53.1, IC4.34 (!RESET), R16.1
unnamed: C46.1, C47.1, IC4.8 (VPLL), L1.1
unnamed: C48.1, C49.1, IC4.3 (VPHY), L3.1
unnamed: IC4.5 (REF), R17.2
unnamed: IC8.4 (DO), R18.2, R19.1
unnamed: IC4.43 (EEDATA), IC8.3 (DI), R18.1
unnamed: C56.2, IC4.2 (XCSO), Q1.1
unnamed: IC4.44 (EECLK), IC8.2 (CLK), R20.1
unnamed: IC4.45 (EECS), IC8.1 (CS), R21.1
unnamed: C55.2, IC4.1 (XCSI), Q1.2
unnamed: IC4.14 (AD1/RXD/TDI/FSCLK), R39.2
unnamed: IC4.16 (AD3/CTS#/TMS/FSCTS), R40.2
unnamed: C74.1, L6.1, R51.1
SK: R38.1; also elsewhere on the board
VCCIO: C44.1, C45.1, C50.1, C51.1, C52.1, C54.1, IC4.12 (VCCIO), IC4.24 (VCCIO), IC4.39 (VCCD), IC4.46 (VCCIO), IC8.6 (ORG), IC8.8 (VCC), L1.2, L3.2, R16.2, R19.2, R20.2, R21.2; also elsewhere on the board

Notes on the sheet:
Rev: 1
By: Trond Egil Gran
Super Scope Pro +2
USB

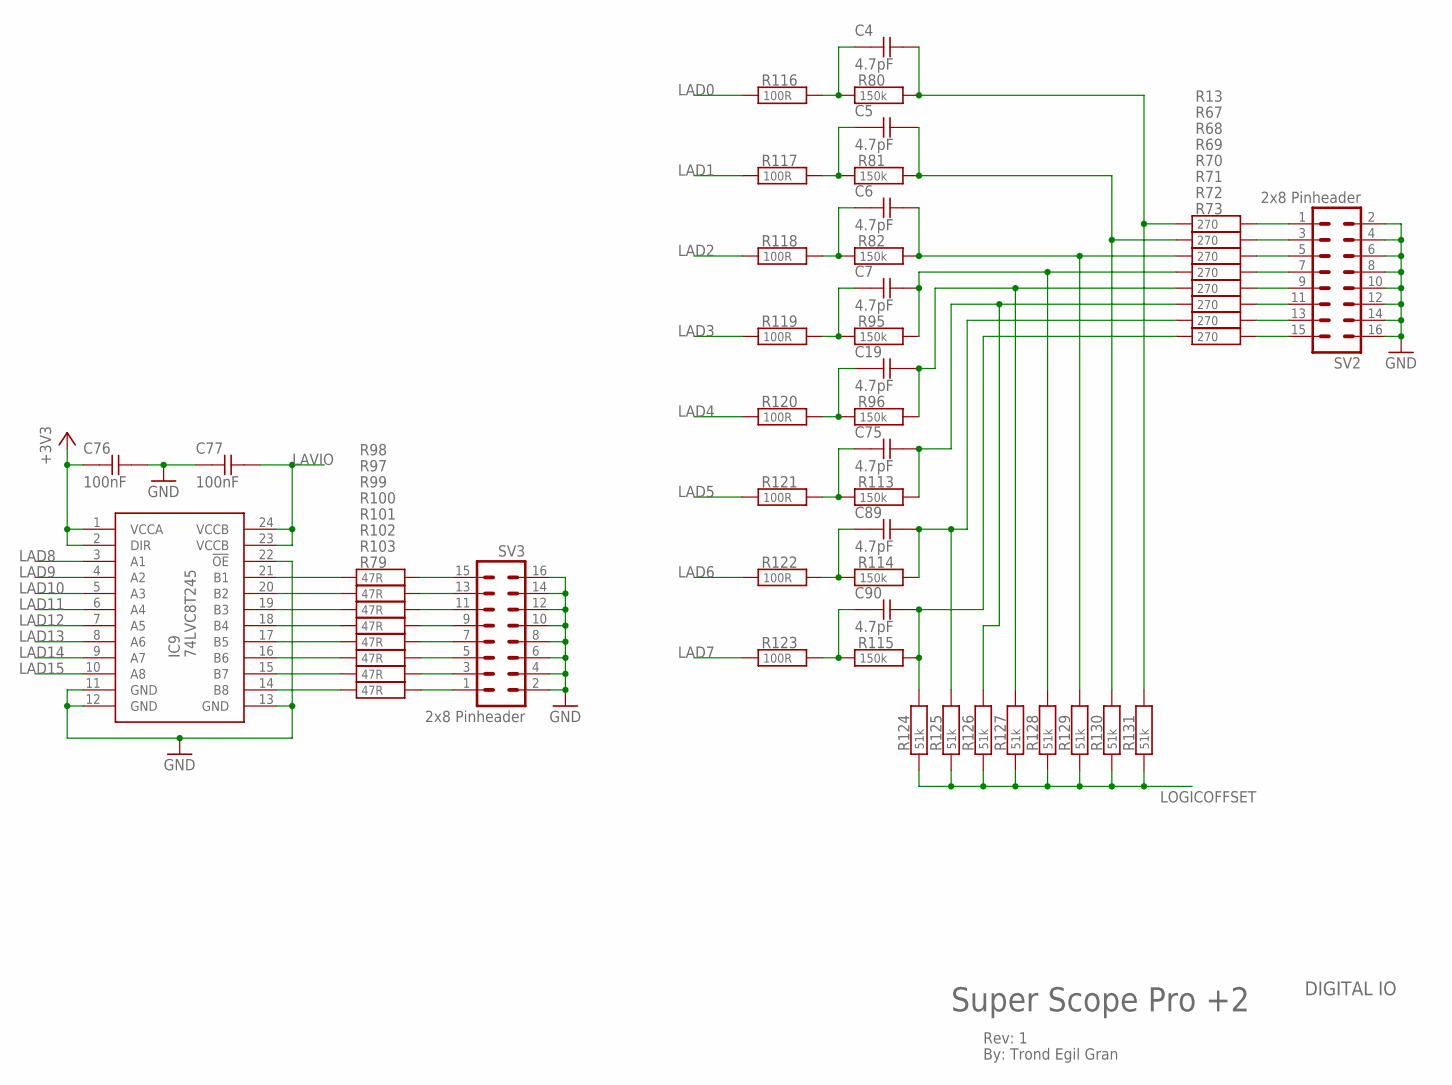
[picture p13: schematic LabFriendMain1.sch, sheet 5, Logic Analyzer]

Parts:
C4, C5, C6, C7, C19, C75, C89, C90: 4.7pF; 0402
C76, C77: 100nF; 0402
IC9: 74LVC8T245; R-PDSO-G24
R13, R67, R68, R69, R70, R71, R72, R73: 270; 0402
R79, R97, R98, R99, R100, R101, R102, R103: 47R; 0402
R80, R81, R82, R95, R96, R113, R114, R115: 150k; 0402
R116, R117, R118, R119, R120, R121, R122, R123: 100R; 0402
R124, R125, R126, R127, R128, R129, R130, R131: 51k; 0402
SV2, SV3: 2x8 Pinheader; MA08-2W

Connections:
+3V3: C76.1, IC9.1 (VCCA), IC9.2 (DIR); also elsewhere on the board
GND: C76.2, C77.1, IC9.11 (GND), IC9.12 (GND), IC9.13 (GND), IC9.22 (!OE), SV2.2, SV2.4, SV2.6, SV2.8, SV2.10, SV2.12, SV2.14, SV2.16, SV3.2, SV3.4, SV3.6, SV3.8, SV3.10, SV3.12, SV3.14, SV3.16; also elsewhere on the board
LAD0: R116.1; also elsewhere on the board
LAD1: R117.1; also elsewhere on the board
LAD2: R118.1; also elsewhere on the board
LAD3: R119.1; also elsewhere on the board
LAD4: R120.1; also elsewhere on the board
LAD5: R121.1; also elsewhere on the board
LAD6: R122.1; also elsewhere on the board
LAD7: R123.1; also elsewhere on the board
LAD8: IC9.3 (A1); also elsewhere on the board
LAD9: IC9.4 (A2); also elsewhere on the board
LAD10: IC9.5 (A3); also elsewhere on the board
LAD11: IC9.6 (A4); also elsewhere on the board
LAD12: IC9.7 (A5); also elsewhere on the board
LAD13: IC9.8 (A6); also elsewhere on the board
LAD14: IC9.9 (A7); also elsewhere on the board
LAD15: IC9.10 (A8); also elsewhere on the board
LAVIO: C77.2, IC9.23 (VCCB), IC9.24 (VCCB); also elsewhere on the board
LOGICOFFSET: R124.1, R125.1, R126.1, R127.1, R128.1, R129.1, R130.1, R131.1; also elsewhere on the board
unnamed: IC9.14 (B8), R79.1
unnamed: R13.2, SV2.1
unnamed: R67.2, SV2.3
unnamed: C4.2, R13.1, R80.2, R131.2
unnamed: C5.2, R67.1, R81.2, R130.2
unnamed: C6.2, R68.1, R82.2, R129.2
unnamed: C7.2, R69.1, R95.2, R128.2
unnamed: C19.2, R70.1, R96.2, R127.2
unnamed: C75.2, R71.1, R113.2, R126.2
unnamed: C89.2, R72.1, R114.2, R125.2
unnamed: C90.2, R73.1, R115.2, R124.2
unnamed: R68.2, SV2.5
unnamed: R69.2, SV2.7
unnamed: R97.2, SV3.15
unnamed: R70.2, SV2.9
unnamed: C4.1, R80.1, R116.2
unnamed: R71.2, SV2.11
unnamed: R72.2, SV2.13
unnamed: R73.2, SV2.15
unnamed: C5.1, R81.1, R117.2
unnamed: C6.1, R82.1, R118.2
unnamed: C7.1, R95.1, R119.2
unnamed: IC9.21 (B1), R97.1
unnamed: R98.2, SV3.13
unnamed: R99.2, SV3.11
unnamed: R100.2, SV3.9
unnamed: R101.2, SV3.7
unnamed: R102.2, SV3.5
unnamed: R103.2, SV3.3
unnamed: R79.2, SV3.1
unnamed: IC9.20 (B2), R98.1
unnamed: IC9.19 (B3), R99.1
unnamed: IC9.18 (B4), R100.1
unnamed: IC9.17 (B5), R101.1
unnamed: IC9.16 (B6), R102.1
unnamed: IC9.15 (B7), R103.1
unnamed: C19.1, R96.1, R120.2
unnamed: C75.1, R113.1, R121.2
unnamed: C89.1, R114.1, R122.2
unnamed: C90.1, R115.1, R123.2

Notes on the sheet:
Rev: 1
By: Trond Egil Gran
Super Scope Pro +2
DIGITAL IO

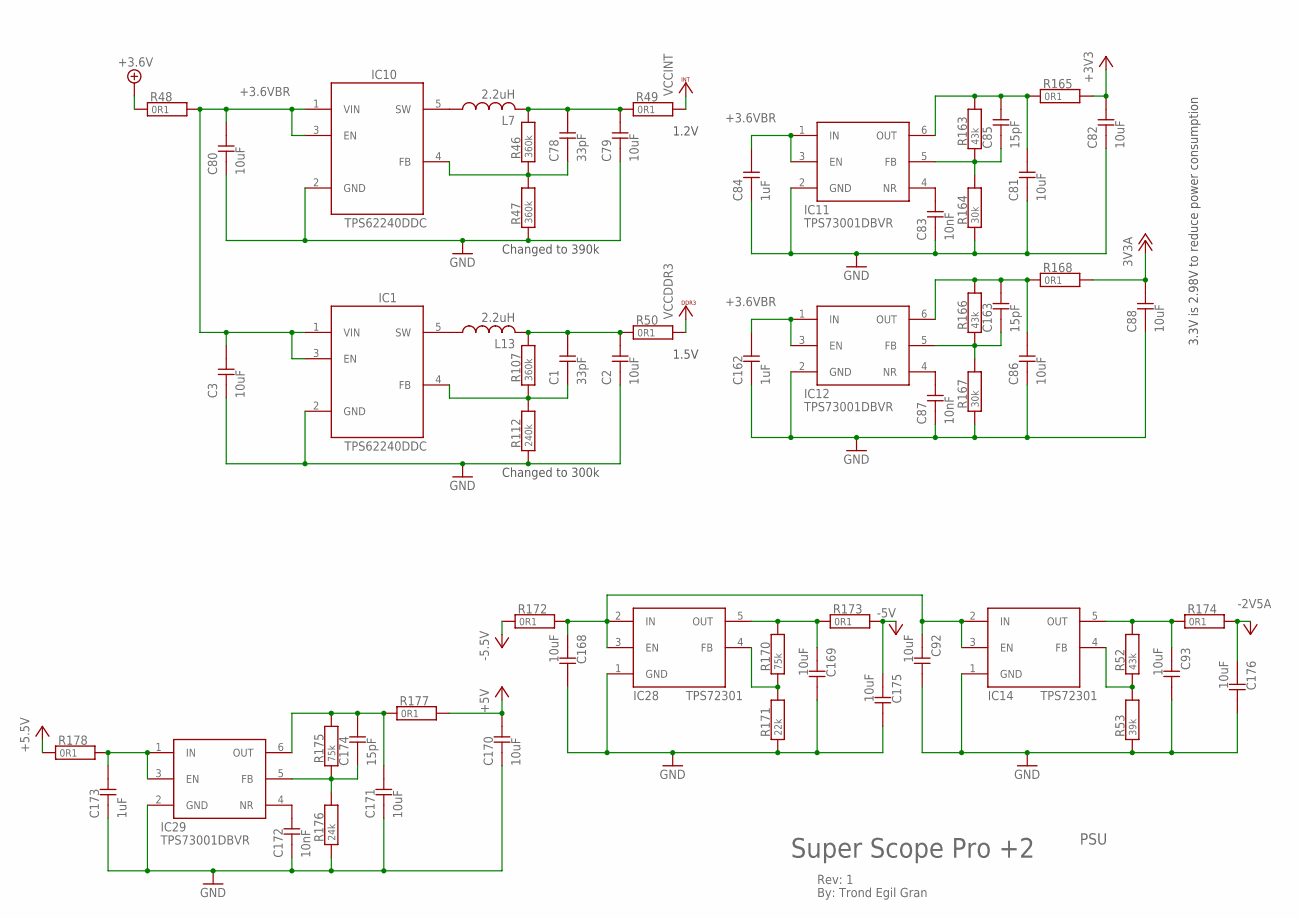
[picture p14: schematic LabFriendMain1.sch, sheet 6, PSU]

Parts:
C1, C78: 33pF; 0603
C2, C3, C79, C80, C81, C82, C86, C88, C92, C93, C168, C169, C170, C171, C175, C176: 10uF; 0603
C83, C87, C172: 10nF; 0402
C84, C162, C173: 1uF; 0603
C85, C163, C174: 15pF; 0603
IC1, IC10: TPS62240DDC; SOT23-5L
IC11, IC12, IC29: TPS73001DBVR; SOT23-6L
IC14, IC28: TPS72301; SOT23-5L
L7, L13: 2.2uH; L3216C
R46, R47, R107: 360k; 0603
R48, R49, R50, R165, R168, R172, R173, R174, R177, R178: 0R1; 0603
R52, R163, R166: 43k; 0603
R53: 39k; 0603
R112: 240k; 0603
R164, R167: 30k; 0603
R170, R175: 75k; 0603
R171: 22k; 0603
R176: 24k; 0603

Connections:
3V3A: C88.2, R168.2; also elsewhere on the board
+3.6V: R48.1; also elsewhere on the board
+3.6VBR: C3.2, C80.2, C84.2, C162.2, IC1.1 (VIN), IC1.3 (EN), IC10.1 (VIN), IC10.3 (EN), IC11.1 (IN), IC11.3 (EN), IC12.1 (IN), IC12.3 (EN), R48.2
+3V3: C82.2, R165.2; also elsewhere on the board
+5.5V: R178.1; also elsewhere on the board
+5.5VI: C173.2, IC29.1 (IN), IC29.3 (EN), R178.2
+5V: C170.2, R177.2; also elsewhere on the board
-2.5VI: C93.1, IC14.5 (OUT), R52.2, R174.1
-2V5A: C176.1, R174.2; also elsewhere on the board
-5.5V: R172.1; also elsewhere on the board
-5V: C175.1, R173.2; also elsewhere on the board
GND: C2.1, C3.1, C79.1, C80.1, C81.1, C82.1, C83.1, C84.1, C86.1, C87.1, C88.1, C92.2, C93.2, C162.1, C168.2, C169.2, C170.1, C171.1, C172.1, C173.1, C175.2, C176.2, IC1.2 (GND), IC10.2 (GND), IC11.2 (GND), IC12.2 (GND), IC14.1 (GND), IC28.1 (GND), IC29.2 (GND), R47.1, R53.1, R112.1, R164.1, R167.1, R171.1, R176.1; also elsewhere on the board
unnamed: C83.2, IC11.4 (NR)
unnamed: C78.1, IC10.4 (FB), R46.1, R47.2
unnamed: IC14.4 (FB), R52.1, R53.2
unnamed: IC10.5 (SW), L7.1
unnamed: C92.1, C168.1, IC14.2 (IN), IC14.3 (EN), IC28.2 (IN), IC28.3 (EN), R172.2
unnamed: C78.2, C79.2, L7.2, R46.2, R49.1
unnamed: C87.2, IC12.4 (NR)
unnamed: C1.2, C2.2, L13.2, R50.1, R107.2
unnamed: C1.1, IC1.4 (FB), R107.1, R112.2
unnamed: IC1.5 (SW), L13.1
unnamed: C81.2, C85.2, IC11.6 (OUT), R163.2, R165.1
unnamed: C85.1, IC11.5 (FB), R163.1, R164.2
unnamed: C86.2, C163.2, IC12.6 (OUT), R166.2, R168.1
unnamed: C163.1, IC12.5 (FB), R166.1, R167.2
unnamed: C169.1, IC28.5 (OUT), R170.2, R173.1
unnamed: IC28.4 (FB), R170.1, R171.2
unnamed: C172.2, IC29.4 (NR)
unnamed: C171.2, C174.2, IC29.6 (OUT), R175.2, R177.1
unnamed: C174.1, IC29.5 (FB), R175.1, R176.2
VCCDDR3: R50.2; also elsewhere on the board
VCCINT: R49.2; also elsewhere on the board

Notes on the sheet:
Rev: 1
By: Trond Egil Gran
Super Scope Pro +2
PSU
3.3V is 2.98V to reduce power consumption
1.2V
1.5V
Changed to 300k
Changed to 390k

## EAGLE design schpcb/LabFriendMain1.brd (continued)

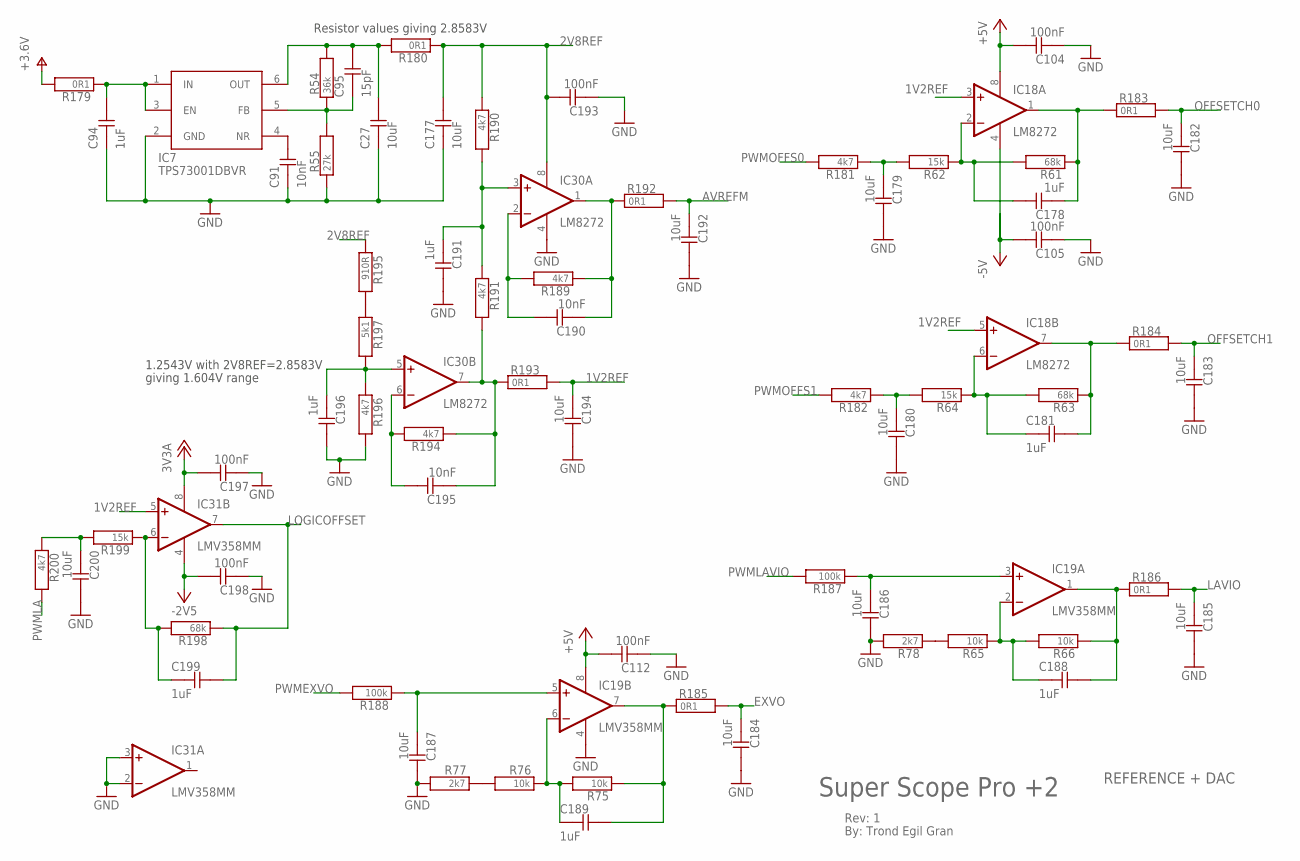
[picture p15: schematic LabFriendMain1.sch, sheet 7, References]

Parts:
C27, C177, C179, C180, C182, C183, C184, C185, C186, C187, C192, C194, C200: 10uF; 0603
C91, C190, C195: 10nF; 0402
C94, C178, C181, C188, C189, C191, C196, C199: 1uF; 0603
C95: 15pF; 0603
C104, C105, C112, C193, C197, C198: 100nF; 0402
IC7: TPS73001DBVR; SOT23-6L
IC18, IC30: LM8272; MSOP08
IC19, IC31: LMV358MM; MSOP08
R54: 36k; 0603
R55: 27k; 0603
R61, R63, R198: 68k; 0603
R62, R64, R199: 15k; 0603
R65, R66, R75, R76: 10k; 0603
R77, R78: 2k7; 0603
R179, R180, R183, R184, R185, R186, R192, R193: 0R1; 0603
R181, R182, R189, R190, R191, R194, R196, R200: 4k7; 0603
R187, R188: 100k; 0603
R195: 910R; 0603
R197: 5k1; 0603

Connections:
1V2REF: C194.1, IC18.3 (+IN), IC18.5 (+IN), IC31.5 (+IN), R193.2; also elsewhere on the board
2V8REF: C177.2, C193.2, IC30.8 (V+), R180.1, R190.1, R195.1; also elsewhere on the board
3V3A: C197.2, IC31.8 (V+); also elsewhere on the board
+3.6V: R179.2; also elsewhere on the board
+3.6VI: C94.2, IC7.1 (IN), IC7.3 (EN), R179.1
+5V: C104.2, C112.2, IC18.8 (V+), IC19.8 (V+); also elsewhere on the board
-2V5A: C198.2, IC31.4 (V-); also elsewhere on the board
-5V: C105.2, IC18.4 (V-); also elsewhere on the board
AVREFM: C192.1, R192.2; also elsewhere on the board
EXVO: C184.1, R185.2; also elsewhere on the board
EXVOI: C189.2, IC19.7 (OUT), R75.1, R185.1
GND: C27.1, C91.1, C94.1, C104.1, C105.1, C112.1, C177.1, C179.2, C180.2, C182.2, C183.2, C184.2, C185.2, C186.2, C187.2, C191.2, C192.2, C193.1, C194.2, C196.2, C197.1, C198.1, C200.2, IC7.2 (GND), IC19.4 (V-), IC30.4 (V-), IC31.2 (-IN), IC31.3 (+IN), R55.1, R77.2, R78.2, R196.2; also elsewhere on the board
LAVIO: C185.1, R186.2; also elsewhere on the board
LAVIOI: C188.2, IC19.1 (OUT), R66.1, R186.1
LOGICOFFSET: C199.2, IC31.7 (OUT), R198.1; also elsewhere on the board
unnamed: C191.1, IC30.3 (+IN), R190.2, R191.1
unnamed: C91.2, IC7.4 (NR)
unnamed: C188.1, IC19.2 (-IN), R65.1, R66.2
unnamed: C178.2, IC18.2 (-IN), R61.2, R62.1
unnamed: C27.2, C95.2, IC7.6 (OUT), R54.2, R180.2
unnamed: C181.1, IC18.6 (-IN), R63.2, R64.1
unnamed: C179.1, R62.2, R181.1
unnamed: C180.1, R64.2, R182.1
unnamed: C186.1, IC19.3 (+IN), R187.1
unnamed: C187.1, IC19.5 (+IN), R188.1
unnamed: R76.2, R77.1
unnamed: C95.1, IC7.5 (FB), R54.1, R55.2
unnamed: C189.1, IC19.6 (-IN), R75.2, R76.1
unnamed: R65.2, R78.1
unnamed: R195.2, R197.1
unnamed: C190.1, IC30.1 (OUT), R189.1, R192.1
unnamed: C190.2, IC30.2 (-IN), R189.2
unnamed: C195.1, IC30.7 (OUT), R191.2, R193.1, R194.1
unnamed: C195.2, IC30.6 (-IN), R194.2
unnamed: C196.1, IC30.5 (+IN), R196.1, R197.2
unnamed: C199.1, IC31.6 (-IN), R198.2, R199.1
unnamed: C200.1, R199.2, R200.1
OFFSETCH0: C182.1, R183.2; also elsewhere on the board
OFFSETCH0I: C178.1, IC18.1 (OUT), R61.1, R183.1
OFFSETCH1: C183.1, R184.2; also elsewhere on the board
OFFSETCH1I: C181.2, IC18.7 (OUT), R63.1, R184.1
PWMEXVO: R188.2; also elsewhere on the board
PWMLA: R200.2; also elsewhere on the board
PWMLAVIO: R187.2; also elsewhere on the board
PWMOFFS0: R181.2; also elsewhere on the board
PWMOFFS1: R182.2; also elsewhere on the board

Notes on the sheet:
Rev: 1
By: Trond Egil Gran
Super Scope Pro +2
REFERENCE + DAC
1.2543V with 2V8REF=2.8583V
giving 1.604V range
Resistor values giving 2.8583V

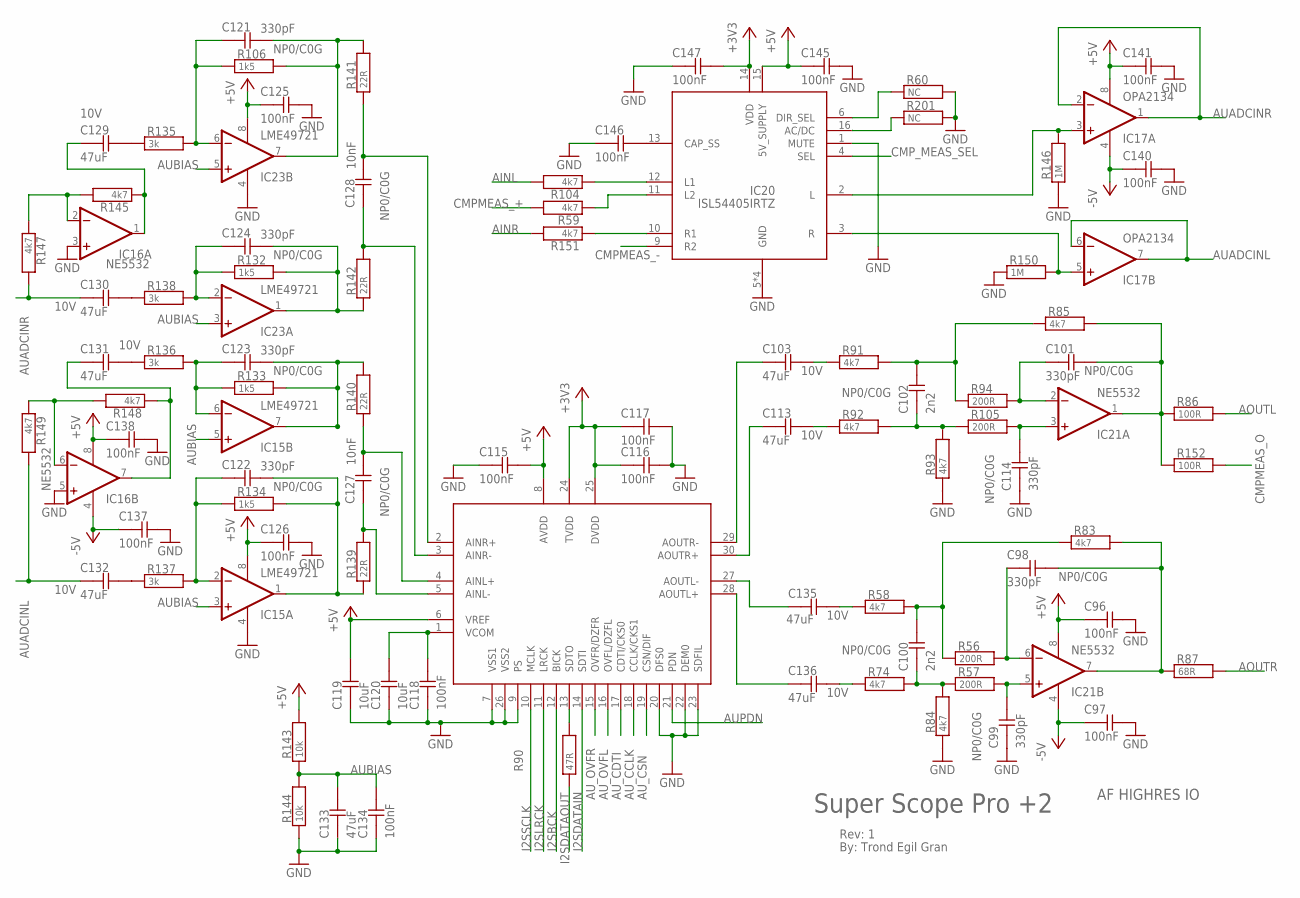
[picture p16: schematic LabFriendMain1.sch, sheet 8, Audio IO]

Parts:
C96, C97, C115, C116, C117, C118, C125, C126, C134, C137, C138, C140, C141, C145, C146, C147: 100nF; 0402
C98, C99, C101, C114, C121, C122, C123, C124: 330pF; 0603
C100, C102: 2n2; 0603
C103, C113, C129, C130, C131, C132, C133, C135, C136: 47uF; 1206; VOLTAGE 10V
C119, C120: 10uF; 0603
C127, C128: 10nF; 0603
IC13: AK4621; VSOP30
IC15, IC23: LME49721; SO08
IC16, IC21: NE5532; SO08
IC17: OPA2134; SO08
IC20: ISL54405IRTZ; TQFN3X3
R56, R57, R94, R105: 200R; 0603
R58, R59, R74, R83, R84, R85, R91, R92, R93, R104, R145, R147, R148, R149, R151: 4k7; 0603
R60, R201: NC; 0402
R86, R152: 100R; 0402
R87: 68R; 0603
R90: 47R; 0402
R106, R132, R133, R134: 1k5; 0603
R135, R136, R137, R138: 3k; 0603
R139, R140, R141, R142: 22R; 0603
R143, R144: 10k; 0603
R146, R150: 1M; 0603

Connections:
+3V3: C116.1, C117.1, C147.2, IC13.24 (TVDD), IC13.25 (DVDD), IC20.14 (VDD); also elsewhere on the board
+5V: C96.1, C115.2, C119.2, C125.1, C126.1, C138.1, C141.1, C145.1, IC13.6 (VREF), IC13.8 (AVDD), IC15.8 (V+), IC16.8 (V+), IC17.8 (V+), IC20.15 (5V_SUPPLY), IC21.8 (V+), IC23.8 (V+), R143.2; also elsewhere on the board
-5V: C97.1, C137.1, C140.1, IC16.4 (V-), IC17.4 (V-), IC21.4 (V-); also elsewhere on the board
AINL: R104.2; also elsewhere on the board
AINR: R151.2; also elsewhere on the board
AOUTL: R86.2; also elsewhere on the board
AOUTR: R87.2; also elsewhere on the board
AUADCINL: C132.1, IC17.6 (-IN), IC17.7 (OUT), R149.2
AUADCINR: C130.1, IC17.1 (OUT), IC17.2 (-IN), R147.2
AUBIAS: C133.2, C134.2, IC15.3 (+IN), IC15.5 (+IN), IC23.3 (+IN), IC23.5 (+IN), R143.1, R144.2
AUPDN: IC13.21 (PDN); also elsewhere on the board
AU_CCLK: IC13.18 (CCLK/CKS1); also elsewhere on the board
AU_CDTI: IC13.17 (CDTI/CKS0); also elsewhere on the board
AU_CSN: IC13.19 (CSN/DIF); also elsewhere on the board
AU_OVFL: IC13.16 (OVFL/DZFL); also elsewhere on the board
AU_OVFR: IC13.15 (OVFR/DZFR); also elsewhere on the board
CMPMEAS_+: R59.2; also elsewhere on the board
CMPMEAS_-: IC20.9 (R2); also elsewhere on the board
CMPMEAS_O: R152.2; also elsewhere on the board
CMP_MEAS_SEL: IC20.4 (SEL); also elsewhere on the board
GND: C96.2, C97.2, C99.1, C114.1, C115.1, C116.2, C117.2, C118.1, C119.1, C120.1, C125.2, C126.2, C133.1, C134.1, C137.2, C138.2, C140.2, C141.2, C145.2, C146.1, C147.1, IC13.7 (VSS1), IC13.9 (PS), IC13.20 (DFS0), IC13.22 (DEM0), IC13.23 (SDFIL), IC13.26 (VSS2), IC15.4 (V-), IC16.3 (+IN), IC16.5 (+IN), IC20.1 (MUTE), IC20.5 (GND), IC20.7 (GND), IC20.8 (GND), IC20.GPD (GND), IC23.4 (V-), R60.2, R84.1, R93.1, R144.1, R146.1, R150.1, R201.2; also elsewhere on the board
I2SBCK: IC13.12 (BICK); also elsewhere on the board
I2SDATAIN: IC13.14 (SDTI); also elsewhere on the board
I2SDATAOUT: R90.1; also elsewhere on the board
I2SLRCK: IC13.11 (LRCK); also elsewhere on the board
I2SSCLK: IC13.10 (MCLK); also elsewhere on the board
unnamed: C98.1, IC21.6 (-IN), R56.2
unnamed: C99.2, IC21.5 (+IN), R57.2
unnamed: C98.2, IC21.7 (OUT), R83.2, R87.1
unnamed: C100.2, R56.1, R58.2, R83.1
unnamed: C100.1, R57.1, R74.2, R84.2
unnamed: C135.2, R58.1
unnamed: C136.2, R74.1
unnamed: C101.2, IC21.1 (OUT), R85.2, R86.1, R152.1
unnamed: C101.1, IC21.2 (-IN), R94.2
unnamed: C114.2, IC21.3 (+IN), R105.2
unnamed: C102.2, R85.1, R91.2, R94.1
unnamed: C121.2, IC23.7 (OUT), R106.2, R141.2
unnamed: C102.1, R92.2, R93.2, R105.1
unnamed: C103.2, R91.1
unnamed: C113.2, R92.1
unnamed: C103.1, IC13.29 (AOUTR-)
unnamed: IC13.13 (SDTO), R90.2
unnamed: C113.1, IC13.30 (AOUTR+)
unnamed: C136.1, IC13.28 (AOUTL+)
unnamed: C135.1, IC13.27 (AOUTL-)
unnamed: C121.1, IC23.6 (-IN), R106.1, R135.2
unnamed: C124.2, IC23.1 (OUT), R132.2, R142.1
unnamed: C123.2, IC15.7 (OUT), R133.2, R140.2
unnamed: C118.2, C120.2, IC13.1 (VCOM)
unnamed: C122.2, IC15.1 (OUT), R134.2, R139.1
unnamed: IC20.12 (L1), R104.1
unnamed: C122.1, IC15.2 (-IN), R134.1, R137.2
unnamed: C123.1, IC15.6 (-IN), R133.1, R136.2
unnamed: C124.1, IC23.2 (-IN), R132.1, R138.2
unnamed: C127.2, IC13.4 (AINL+), R140.1
unnamed: C127.1, IC13.5 (AINL-), R139.2
unnamed: C128.1, IC13.3 (AINR-), R142.2
unnamed: C128.2, IC13.2 (AINR+), R141.1
unnamed: C129.2, R135.1
unnamed: C130.2, R138.1
unnamed: C131.2, R136.1
unnamed: C132.2, R137.1
unnamed: C131.1, IC16.7 (OUT), R148.1
unnamed: IC17.5 (+IN), IC20.3 (R), R150.2
unnamed: IC17.3 (+IN), IC20.2 (L), R146.2
unnamed: C146.2, IC20.13 (CAP_SS)
unnamed: C129.1, IC16.1 (OUT), R145.1
unnamed: IC16.2 (-IN), R145.2, R147.1
unnamed: IC16.6 (-IN), R148.2, R149.1
unnamed: IC20.10 (R1), R151.1
unnamed: IC20.11 (L2), R59.1
unnamed: IC20.16 (AC/DC), R201.1
unnamed: IC20.6 (DIR_SEL), R60.1

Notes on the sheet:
Rev: 1
By: Trond Egil Gran
Super Scope Pro +2
AF HIGHRES IO

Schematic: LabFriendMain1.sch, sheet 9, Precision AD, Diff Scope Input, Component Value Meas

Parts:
C139, C148, C150, C204: 100nF; 0402
C201, C202, C203: 10nF; 0402
IC22: 74HC4052D; SO16
IC25: INA331IDGK; MSOP08
IC32: ADS1118IDGSR; MSOP10
R108, R109, R110, R111: 4k7; 0402
R153: 1M; 0603
R154: 100k; 0603
R155: 1k; 0603
R156: 68R; 0603
R202: 91k; 0603
R203: 10k; 0603
R204, R205: 27k; 0603
R206, R207: 22k; 0603
R280: 1k; 0402
R281: 2k2; 0402
SV4: 2x8 Pinheader; MA08-2W
SV5: 3x1 Pinheader; MA03-1

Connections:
+5V: C139.1, C148.1, C204.2, IC22.16 (VCC), IC25.7 (V+), IC25.8 (SD), IC32.8 (VDD); also elsewhere on the board
-5V: C150.2, IC22.7 (VEE); also elsewhere on the board
AINL: SV4.8; also elsewhere on the board
AINR: SV4.7; also elsewhere on the board
AOUTL: SV4.6; also elsewhere on the board
AOUTR: SV4.5; also elsewhere on the board
AUXINCH0: IC25.6 (VOUT), R202.2; also elsewhere on the board
AU_CCLK: IC32.1 (SCLK); also elsewhere on the board
AU_CDTI: IC32.10 (DIN); also elsewhere on the board
AVREFM: IC25.5 (REF), R203.1, R206.2, R207.1; also elsewhere on the board
CMPMEAS_+: R153.1, R154.1, R155.1, R156.1, SV4.1; also elsewhere on the board
CMPMEAS_-: IC22.3 (Y); also elsewhere on the board
CMPMEAS_A: IC22.10 (A); also elsewhere on the board
CMPMEAS_B: IC22.9 (B); also elsewhere on the board
CMPMEAS_EN: IC22.6 (INH); also elsewhere on the board
CMPMEAS_O: IC22.13 (X); also elsewhere on the board
DC_CS: IC32.2 (!CS); also elsewhere on the board
DC_DOUT: R280.1, R281.1; also elsewhere on the board
EXVO: R111.1, SV4.2; also elsewhere on the board
GND: C139.2, C148.2, C150.1, C201.2, C202.2, C203.2, C204.1, IC22.8 (GND), IC25.4 (V-), IC32.3 (GND), R281.2, SV4.3, SV4.4, SV4.9, SV4.10, SV4.12, SV4.13, SV5.2; also elsewhere on the board
HFDAC: SV4.11; also elsewhere on the board
unnamed: C203.1, IC32.4 (AIN0), R108.2
unnamed: C202.1, IC32.5 (AIN1), R109.2
unnamed: C201.1, IC32.6 (AIN2), R110.2
unnamed: R108.1, SV4.15
unnamed: R109.1, SV4.16
unnamed: IC32.7 (AIN3), R111.2
unnamed: R110.1, SV4.14
unnamed: IC22.1 (Y0), IC22.12 (X0), R153.2
unnamed: IC22.5 (Y1), IC22.14 (X1), R154.2
unnamed: IC22.2 (Y2), IC22.15 (X2), R155.2
unnamed: IC22.4 (Y3), IC22.11 (X3), R156.2
unnamed: IC25.1 (RG), R202.1, R203.2
unnamed: IC25.3 (VIN+), R204.2, R207.2
unnamed: IC25.2 (VIN-), R205.2, R206.1
unnamed: R204.1, SV5.3
unnamed: R205.1, SV5.1
unnamed: IC32.9 (DOUT/!DRDY), R280.2

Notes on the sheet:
Rev: 1
By: Trond Egil Gran
Super Scope Pro +2
LS ANALOG IN

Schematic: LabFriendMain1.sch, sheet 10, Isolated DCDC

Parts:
C149: 100pF; 0603
C151, C152: 47pF; 0603
C153, C154, C155, C156, C160: 100nF; 0402
C157, C158, C159, C161: 100uF; CT6032
D1, D2, D3, D4, D5, D6: SK14; DO214AC
IC24: 74HC00D; SO14
IC27: 74HCT132D; SO14
Q2, Q3: FDN335N; SOT23
R157, R158: 10k; 0603
R159, R160: 1k5; 0603
R161, R162: 150R; 0603
T1: EFD15DCDCPM5P33EFD15; B66414-W1008-D1

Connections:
+3.6V: C160.1, C161.+, D5.C, D6.C; also elsewhere on the board
+5.5V: C156.1, C157.+, D1.C, D2.C; also elsewhere on the board
+UB: C153.2, C154.2, C159.+, IC24.14 (VCC), IC27.14 (VCC), T1.2 (P1M); also elsewhere on the board
-5.5V: C155.2, C158.-, D3.A, D4.A; also elsewhere on the board
GND: C155.1, C156.2, C157.-, C158.+, C160.2, C161.-, T1.4 (SM); also elsewhere on the board
GNDIO: C151.1, C152.1, C153.1, C154.1, C159.-, IC24.7 (GND), IC27.7 (GND), Q2.2 (S), Q3.2 (S); also elsewhere on the board
unnamed: IC27.1 (I0), IC27.2 (I1), R157.1
unnamed: IC24.4 (I0), IC24.5 (I1), IC27.3 (O)
unnamed: C149.1, R157.2, R158.1
unnamed: C149.2, IC24.1 (I0), IC24.2 (I1), IC24.6 (O)
unnamed: IC24.3 (O), IC27.4 (I0), IC27.5 (I1), IC27.12 (I0), R158.2, R160.1
unnamed: C151.2, IC27.13 (I1), R160.2
unnamed: IC27.6 (O), IC27.9 (I0), R159.1
unnamed: C152.2, IC27.10 (I1), R159.2
unnamed: IC24.9 (I0), IC24.10 (I1), IC27.8 (O)
unnamed: IC24.12 (I0), IC24.13 (I1), IC27.11 (O)
unnamed: IC24.11 (O), R161.1
unnamed: IC24.8 (O), R162.1
unnamed: Q3.1 (G), R162.2
unnamed: D2.A, D3.C, T1.8 (S1P)
unnamed: D1.A, D4.C, T1.7 (S1N)
unnamed: Q2.3 (D), T1.1 (P1P)
unnamed: Q2.1 (G), R161.2
unnamed: Q3.3 (D), T1.3 (P1N)
unnamed: D5.A, T1.5 (S2P)
unnamed: D6.A, T1.6 (S2N)

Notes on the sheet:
Changed to 82p

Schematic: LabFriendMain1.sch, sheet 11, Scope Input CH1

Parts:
C205: 10uF; 0603
C206, C207, C208, C209, C210, C218, C219, C220, C221, C225, C226, C227: 100nF; 0402
C211: 100nF; 0603; VOLTAGE 50V
C212, C214, C217, C222, C223: 12pF; 0603
C213, C216: 6/30; CTRIMTZBX4
C215: 220pF; 0603
C224: 100uF; 1206
C228, C229: 1pF; 0603
IC33: ADA4853-3RU; SO14
IC34, IC35: 4052D; SO16
IC36: OPA2354; MSOP08
IC37: 74HC595D; SO16
K1, K2: G6K-2F-Y
L12: 1uH; L3216C
R208: 200R; 0603
R209: 30R; 0603
R210: 20R; 0603
R211, R214, R217, R237, R239: 22R; 0603
R212, R215, R216, R229, R230, R238: 300R; 0603
R213: 100R; 0603
R218, R219, R220: 10k; 0603
R221, R222: 30k; 0603
R223, R224: 470k; 0603
R225: 51k; 0603
R226: 39k; 0603
R227: 910k; 0603
R228: 1k; 0603
R231: 7R5; 0603
R232, R233, R234, R235, R236: 10R; 0603
R240: 1R; 0603
R241: 100R; 0402
R242, R243: 47R; 0603
T2, T3, T4, T8: BC850; SOT23
T5, T6, T7, T9: BC856ASMD; SOT23-BEC
X2: 31-5431-10RFX; AMP_227161

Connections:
3V3A: C218.2, IC36.8 (V+); also elsewhere on the board
+5V: C205.2, C206.2, C208.2, C210.2, C221.2, IC33.4 (V+), IC34.16 (VCC), IC35.16 (VCC), IC37.10 (SCL), IC37.16 (VCC), R232.2; also elsewhere on the board
-2V5A: C207.1, C209.1, C219.1, IC34.7 (VEE), IC35.7 (VEE), IC36.4 (V-); also elsewhere on the board
ATTRL+: IC37.1 (QB), R234.2
ATTRL-: IC37.15 (QA), R236.1
AUXIN: IC34.11 (X3); also elsewhere on the board
AUXOUT: R239.2
AVREFM: C225.1, C226.1, C227.1, R210.1, R213.1, R216.1, R218.1, R219.1, R220.1; also elsewhere on the board
DCRL+: IC37.3 (QD), R235.2
DCRL-: IC37.2 (QC), R233.1
GMUXA: IC34.10 (A), IC37.4 (QE)
GMUXB: IC34.9 (B), IC37.5 (QF)
GMUXC: IC35.10 (A), IC37.6 (QG)
GMUXD: IC35.9 (B), IC37.7 (QH)
GND: C205.1, C206.1, C207.2, C208.1, C209.2, C210.1, C212.1, C213.2 (A), C215.1, C216.2 (A), C218.1, C219.2, C220.1, C221.1, C224.2, C225.2, C226.2, C227.2, IC33.1 (!POWERDOWN), IC33.2 (!POWERDOWN), IC33.3 (!POWERDOWN), IC33.11 (V-), IC34.6 (INH), IC34.8 (GND), IC35.6 (INH), IC35.8 (GND), IC37.8 (GND), IC37.13 (G), R224.1, R228.1, R240.1, T5.C, T6.C, T7.C, T9.C; also elsewhere on the board
unnamed: IC33.6 (IN-), R208.1, R209.2
unnamed: IC33.7 (OUT), R208.2, R211.2
unnamed: R209.1, R210.2
unnamed: IC33.9 (IN-), R212.1, R213.2
unnamed: IC33.13 (IN-), R215.1, R216.2
unnamed: IC33.14 (OUT), R215.2, R217.2
unnamed: IC33.5 (IN+), IC34.12 (X0), IC35.5 (Y1), IC35.15 (X2), R220.2, R231.1
unnamed: IC33.8 (OUT), R212.2, R214.2
unnamed: IC35.1 (Y0), IC35.11 (X3), R211.1
unnamed: IC33.12 (IN+), IC35.13 (X), R219.2
unnamed: IC34.14 (X1), IC35.12 (X0), R214.1
unnamed: IC34.15 (X2), R217.1
unnamed: IC33.10 (IN+), IC35.3 (Y), R218.2
unnamed: C211.2, K1.3, R241.1
unnamed: C211.1, K1.2 (O), K2.3
unnamed: R221.2, R223.1
unnamed: C212.2, C214.1, C228.1, R221.1, R222.2, R242.2
unnamed: R222.1, R224.2
unnamed: C214.2, C223.2, C228.2, K2.4 (S), R223.2
unnamed: R225.2, R227.1
unnamed: R226.1, R228.2
unnamed: C217.2, C222.2, C229.2, K2.2 (O), R227.2
unnamed: IC36.2 (-IN), R229.1, R230.2
unnamed: IC36.1 (OUT), R229.2, R231.2
unnamed: IC34.13 (X), IC36.5 (+IN)
unnamed: C224.1, R232.1, T2.3 (C), T3.3 (C), T4.3 (C), T8.3 (C)
unnamed: K1.8 (-), T3.2 (E), T6.E
unnamed: K1.1 (+), T2.2 (E), T5.E
unnamed: R235.1, T2.1 (B), T5.B
unnamed: R233.2, T3.1 (B), T6.B
unnamed: K2.1 (+), T4.2 (E), T7.E
unnamed: K2.8 (-), T8.2 (E), T9.E
unnamed: R234.1, T4.1 (B), T7.B
unnamed: R236.2, T8.1 (B), T9.B
unnamed: IC36.7 (OUT), R237.2, R238.2, R239.1
unnamed: IC36.3 (+IN), K2.6
unnamed: C216.1 (E), C222.1
unnamed: C213.1 (E), C223.1
unnamed: IC36.6 (-IN), R238.1
unnamed: C220.2, L12.1, R230.1
unnamed: C215.2, C217.1, C229.1, R225.1, R226.2, R243.2
unnamed: R240.2, X2.2
unnamed: R241.2, X2.1
unnamed: K2.5 (S), R242.1
unnamed: K2.7 (O), R243.1
OFFSETCH1: L12.2; also elsewhere on the board
OUTPUTCH1: R237.1; also elsewhere on the board
SPICHAIN: IC37.9 (QH*); also elsewhere on the board
SPICLK: IC37.11 (SCK); also elsewhere on the board
SPICS: IC37.12 (RCK); also elsewhere on the board
SPIDI: IC37.14 (SER); also elsewhere on the board

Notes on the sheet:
SPIDI SPICLK SPICS SPICHAIN
OUTPUT AUXOUT AUXIN +5V -2.5VA +3VA

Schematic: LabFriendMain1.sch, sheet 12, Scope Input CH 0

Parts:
C230: 10uF; 0603
C231, C232, C233, C234, C235, C243, C244, C245, C246, C250, C251, C252: 100nF; 0402
C236: 100nF; 0603; VOLTAGE 50V
C237, C239, C242, C247, C248: 12pF; 0603
C238, C241: 6/30; CTRIMTZBX4
C240: 220pF; 0603
C249: 100uF; 1206
C253, C254: 1pF; 0603
IC38: ADA4853-3RU; SO14
IC39, IC40: 4052D; SO16
IC41: OPA2354; MSOP08
IC42: 74HC595D; SO16
K3, K4: G6K-2F-Y
L14: 1uH; L3216C
R244: 200R; 0603
R245: 30R; 0603
R246: 20R; 0603
R247, R250, R253, R273, R275, R278, R279: 22R; 0603
R248, R251, R252, R265, R266, R274: 300R; 0603
R249, R277: 100R; 0603
R254, R255, R256: 10k; 0603
R257, R258: 30k; 0603
R259, R260: 470k; 0603
R261: 130k; 0603
R262: 47k; 0603
R263: 820k; 0603
R264: 3k; 0603
R267: 7R5; 0603
R268, R269, R270, R271, R272: 10R; 0603
R276: 1R; 0603
T10, T11, T14, T16: BC850; SOT23
T12, T13, T15, T17: BC856ASMD; SOT23-BEC
X3: 31-5431-10RFX; AMP_227161

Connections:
3V3A: C243.2, IC41.8 (V+); also elsewhere on the board
+5V: C230.2, C231.2, C233.2, C235.2, C246.2, IC38.4 (V+), IC39.16 (VCC), IC40.16 (VCC), IC42.10 (SCL), IC42.16 (VCC), R268.2; also elsewhere on the board
-2V5A: C232.1, C234.1, C244.1, IC39.7 (VEE), IC40.7 (VEE), IC41.4 (V-); also elsewhere on the board
ATTRL+B: IC42.1 (QB), R270.2
ATTRL-B: IC42.15 (QA), R272.1
AUXIN: R275.2; also elsewhere on the board
AUXINCH0: IC39.11 (X3); also elsewhere on the board
AVREFM: C250.1, C251.1, C252.1, R246.1, R249.1, R252.1, R254.1, R255.1, R256.1; also elsewhere on the board
DCRL+B: IC42.3 (QD), R271.2
DCRL-B: IC42.2 (QC), R269.1
GMUXAB: IC39.10 (A), IC42.4 (QE)
GMUXBB: IC39.9 (B), IC42.5 (QF)
GMUXCB: IC40.10 (A), IC42.6 (QG)
GMUXDB: IC40.9 (B), IC42.7 (QH)
GND: C230.1, C231.1, C232.2, C233.1, C234.2, C235.1, C237.1, C238.2 (A), C240.1, C241.2 (A), C243.1, C244.2, C245.1, C246.1, C249.2, C250.2, C251.2, C252.2, IC38.1 (!POWERDOWN), IC38.2 (!POWERDOWN), IC38.3 (!POWERDOWN), IC38.11 (V-), IC39.6 (INH), IC39.8 (GND), IC40.6 (INH), IC40.8 (GND), IC42.8 (GND), IC42.13 (G), R260.1, R264.1, R276.1, T12.C, T13.C, T15.C, T17.C; also elsewhere on the board
unnamed: IC38.6 (IN-), R244.1, R245.2
unnamed: IC38.7 (OUT), R244.2, R247.2
unnamed: R245.1, R246.2
unnamed: IC38.9 (IN-), R248.1, R249.2
unnamed: IC38.13 (IN-), R251.1, R252.2
unnamed: IC38.14 (OUT), R251.2, R253.2
unnamed: IC38.5 (IN+), IC39.12 (X0), IC40.5 (Y1), IC40.15 (X2), R256.2, R267.1
unnamed: IC38.8 (OUT), R248.2, R250.2
unnamed: IC40.1 (Y0), IC40.11 (X3), R247.1
unnamed: IC38.12 (IN+), IC40.13 (X), R255.2
unnamed: IC39.14 (X1), IC40.12 (X0), R250.1
unnamed: IC39.15 (X2), R253.1
unnamed: IC38.10 (IN+), IC40.3 (Y), R254.2
unnamed: C236.2, K3.3, R277.1
unnamed: C236.1, K3.2 (O), K4.3
unnamed: R257.2, R259.1
unnamed: C237.2, C239.1, C253.1, R257.1, R258.2, R278.2
unnamed: R258.1, R260.2
unnamed: C239.2, C248.2, C253.2, K4.4 (S), R259.2
unnamed: R261.2, R263.1
unnamed: R262.1, R264.2
unnamed: C242.2, C247.2, C254.2, K4.2 (O), R263.2
unnamed: IC41.2 (-IN), R265.1, R266.2
unnamed: IC41.1 (OUT), R265.2, R267.2
unnamed: IC39.13 (X), IC41.5 (+IN)
unnamed: C249.1, R268.1, T10.3 (C), T11.3 (C), T14.3 (C), T16.3 (C)
unnamed: K3.8 (-), T11.2 (E), T13.E
unnamed: K3.1 (+), T10.2 (E), T12.E
unnamed: R271.1, T10.1 (B), T12.B
unnamed: R269.2, T11.1 (B), T13.B
unnamed: K4.1 (+), T14.2 (E), T15.E
unnamed: K4.8 (-), T16.2 (E), T17.E
unnamed: R270.1, T14.1 (B), T15.B
unnamed: R272.2, T16.1 (B), T17.B
unnamed: IC41.7 (OUT), R273.2, R274.2, R275.1
unnamed: IC41.3 (+IN), K4.6
unnamed: C241.1 (E), C247.1
unnamed: C238.1 (E), C248.1
unnamed: IC41.6 (-IN), R274.1
unnamed: C245.2, L14.1, R266.1
unnamed: C240.2, C242.1, C254.1, R261.1, R262.2, R279.2
unnamed: R276.2, X3.2
unnamed: R277.2, X3.1
unnamed: K4.5 (S), R278.1
unnamed: K4.7 (O), R279.1
OFFSETCH0: L14.2; also elsewhere on the board
OUTPUTCH0: R273.1; also elsewhere on the board
SPICHAIN: IC42.14 (SER); also elsewhere on the board
SPICHAINB: IC42.9 (QH*)
SPICLK: IC42.11 (SCK); also elsewhere on the board
SPICS: IC42.12 (RCK); also elsewhere on the board

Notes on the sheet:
SPIDI SPICLK SPICS SPICHAIN
OUTPUT AUXOUT AUXIN +5V -2.5VA +3VA

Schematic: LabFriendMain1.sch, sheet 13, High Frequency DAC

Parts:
C255, C256: 100nF; 0402
IC43: LM321MF; SOT23-5
IC44: 74HC595D; SO16
R282: 50R; 0603
R283, R285, R292, R293, R294, R295, R296, R297, R298: 1k6; 0603
R284, R286, R287, R288, R289, R290, R291: 820R; 0603
R299: 39R; 0603
R300: 300R; 0603

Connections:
+5V: C255.1, C256.1, IC43.5 (V+), IC44.10 (SCL), IC44.16 (VCC); also elsewhere on the board
GND: C255.2, C256.2, IC43.2 (V-), IC44.8 (GND), IC44.13 (G), R299.1; also elsewhere on the board
HFDAC: R282.2; also elsewhere on the board
HFDAC_CLK: IC44.11 (SCK); also elsewhere on the board
HFDAC_CS: IC44.12 (RCK); also elsewhere on the board
HFDAC_DI: IC44.14 (SER); also elsewhere on the board
unnamed: R284.1, R285.1, R286.2
unnamed: R286.1, R287.2, R293.1
unnamed: R287.1, R288.2, R294.1
unnamed: R288.1, R289.2, R295.1
unnamed: R289.1, R290.2, R296.1
unnamed: R290.1, R291.2, R297.1
unnamed: R291.1, R292.2, R298.1
unnamed: R292.1, R299.2
unnamed: IC43.1 (+IN), R283.2, R284.2
unnamed: IC44.15 (QA), R283.1
unnamed: IC44.1 (QB), R285.2
unnamed: IC44.2 (QC), R293.2
unnamed: IC44.3 (QD), R294.2
unnamed: IC44.4 (QE), R295.2
unnamed: IC44.5 (QF), R296.2
unnamed: IC44.6 (QG), R297.2
unnamed: IC44.7 (QH), R298.2
unnamed: IC43.3 (-IN), R300.1
unnamed: IC43.4 (OUT), R282.1, R300.2

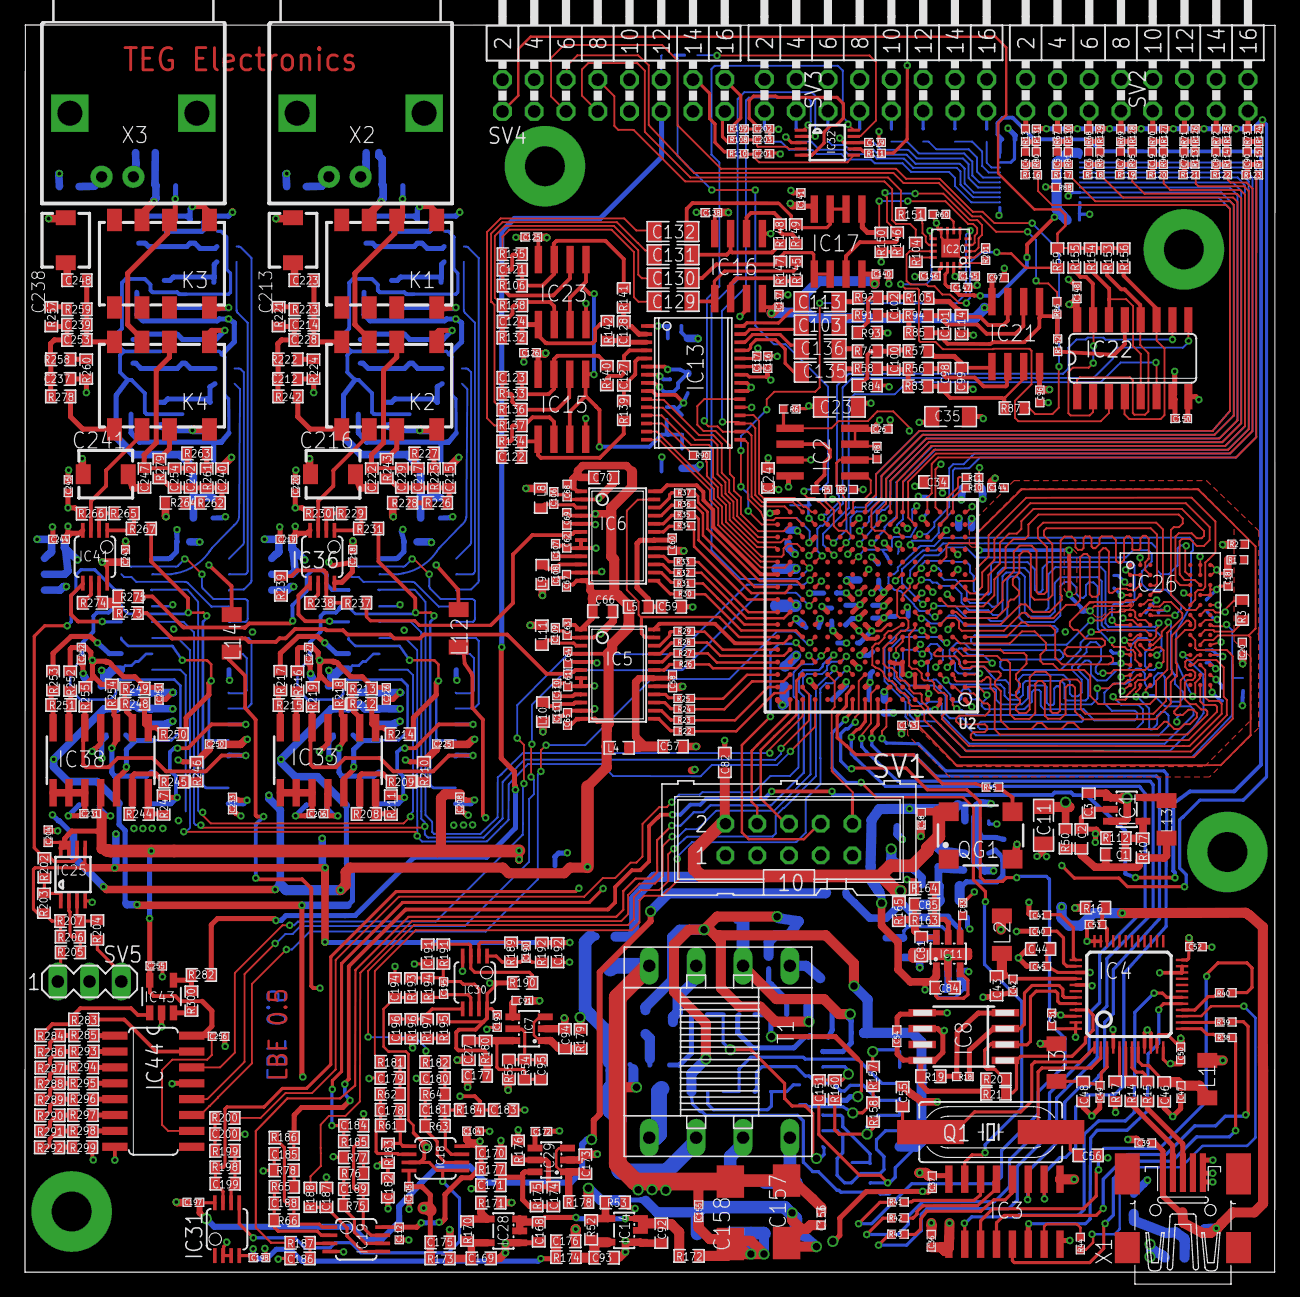
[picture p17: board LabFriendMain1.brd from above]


Board: 4 copper layers, 100.0 x 99.8 mm, 654 parts (145 on the bottom side), 517 nets.

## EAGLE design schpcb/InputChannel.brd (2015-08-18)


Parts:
C1: 10uF; 0603
C2, C3, C5, C6, C7, C8, C9, C11: 100nF; 0603
C4, C14, C16, C19, C21: 100nF; 0402
C10: 100uF; 1206
C12, C15, C20, C26, C27: 12pF; 0603
C13, C18: 6/30; CTRIMTZBX4
C17: 220pF; 0603
C22, C23: 1pF; 0603
IC1: ADA4853-3RU; SO14
IC2, IC3: 4052D; SO16
IC4: OPA2354; MSOP08
IC7: 74HC595D; SO16
K1, K2: G6K-2F-Y
L1: 1uH; L3216C
R1: 200R; 0603
R2: 30R; 0603
R3: 20R; 0603
R4, R8, R12, R32, R37: 22R; 0603
R5, R9, R10, R22, R23, R33: 300R; 0603
R6, R26: 100R; 0603
R7, R15: 30k; 0603
R11, R13, R14: 10k; 0603
R16, R17: 470k; 0603
R18: 51k; 0603
R19: 39k; 0603
R20: 910k; 0603
R21: 1k; 0603
R24: 7R5; 0603
R25: 1R; 0603
R27, R28, R29, R30, R31: 10R; 0603
R34, R35: 47R; 0603
T1, T2, T3, T4: BC850; SOT23
T5, T6, T7, T8: BC856ASMD; SOT23-BEC
X1: 31-5431-10RFX; AMP_227161

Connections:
+3VA: C3.2, IC4.8 (V+)
+5V: C1.2, C2.2, C6.2, C8.2, C9.2, IC1.4 (V+), IC2.16 (VCC), IC3.16 (VCC), IC7.10 (SCL), IC7.16 (VCC), R27.2
-2V5A: C4.1, C5.1, C7.1, IC2.7 (VEE), IC3.7 (VEE), IC4.4 (V-)
ATTRL+: IC7.1 (QB), R29.2
ATTRL-: IC7.15 (QA), R31.1
AUXIN: IC3.11 (X3)
AUXOUT: R37.2
AVREFM: C14.1, C16.1, C19.1, R3.1, R6.1, R10.1, R11.1, R13.1, R14.1
DCRL+: IC7.3 (QD), R30.2
DCRL-: IC7.2 (QC), R28.1
GMUXA: IC3.10 (A), IC7.4 (QE)
GMUXB: IC3.9 (B), IC7.5 (QF)
GMUXC: IC2.10 (A), IC7.6 (QG)
GMUXD: IC2.9 (B), IC7.7 (QH)
GND: C1.1, C2.1, C3.1, C4.2, C5.2, C6.1, C7.2, C8.1, C9.1, C10.2, C12.1, C13.2 (A), C14.2, C16.2, C17.1, C18.2 (A), C19.2, C21.1, IC1.1 (!POWERDOWN), IC1.2 (!POWERDOWN), IC1.3 (!POWERDOWN), IC1.11 (V-), IC2.6 (INH), IC2.8 (GND), IC3.6 (INH), IC3.8 (GND), IC7.8 (GND), IC7.13 (G), R17.1, R21.1, R25.1, T5.C, T6.C, T7.C, T8.C
INSTOUT: IC2.2 (Y2), IC2.14 (X1)
unnamed: IC1.6 (IN-), R1.1, R2.2
unnamed: IC1.7 (OUT), R1.2, R4.2
unnamed: R2.1, R3.2
unnamed: C11.2, K1.3, R26.1
unnamed: IC1.9 (IN-), R5.1, R6.2
unnamed: IC2.1 (Y0), IC2.11 (X3), R4.1
unnamed: C11.1, K1.2 (O), K2.3
unnamed: IC2.12 (X0), IC3.14 (X1), R8.1
unnamed: IC1.12 (IN+), IC2.13 (X), R13.2
unnamed: IC1.5 (IN+), IC2.5 (Y1), IC2.15 (X2), IC3.12 (X0), R14.2, R24.1
unnamed: R7.2, R16.1
unnamed: IC1.13 (IN-), R9.1, R10.2
unnamed: IC1.14 (OUT), R9.2, R12.2
unnamed: IC3.15 (X2), R12.1
unnamed: IC1.8 (OUT), R5.2, R8.2
unnamed: C12.2, C15.1, C22.1, R7.1, R15.2, R34.2
unnamed: IC1.10 (IN+), IC2.3 (Y), R11.2
unnamed: R18.2, R20.1
unnamed: C17.2, C20.1, C23.1, R18.1, R19.2, R35.2
unnamed: R15.1, R17.2
unnamed: C15.2, C22.2, C27.2, K2.4 (S), R16.2
unnamed: R19.1, R21.2
unnamed: C20.2, C23.2, C26.2, K2.2 (O), R20.2
unnamed: R25.2, X1.2
unnamed: IC4.3 (+IN), K2.6
unnamed: C21.2, L1.1, R23.1
unnamed: IC4.2 (-IN), R22.1, R23.2
unnamed: IC4.1 (OUT), R22.2, R24.2
unnamed: R26.2, X1.1
unnamed: K2.5 (S), R34.1
unnamed: IC3.13 (X), IC4.5 (+IN)
unnamed: C10.1, R27.1, T1.3 (C), T2.3 (C), T3.3 (C), T4.3 (C)
unnamed: IC4.7 (OUT), R32.2, R33.2, R37.1
unnamed: K1.8 (-), T2.2 (E), T6.E
unnamed: K1.1 (+), T1.2 (E), T5.E
unnamed: R30.1, T1.1 (B), T5.B
unnamed: R28.2, T2.1 (B), T6.B
unnamed: K2.1 (+), T3.2 (E), T7.E
unnamed: K2.8 (-), T4.2 (E), T8.E
unnamed: IC4.6 (-IN), R33.1
unnamed: R29.1, T3.1 (B), T7.B
unnamed: R31.2, T4.1 (B), T8.B
unnamed: K2.7 (O), R35.1
unnamed: C18.1 (E), C26.1
unnamed: C13.1 (E), C27.1
OFFSETADJUST: L1.2
OUTPUT: R32.1
SPICHAIN: IC7.9 (QH*)
SPICLK: IC7.11 (SCK)
SPICS: IC7.12 (RCK)
SPIDI: IC7.14 (SER)

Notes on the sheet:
SPIDI SPICLK SPICS SPICHAIN
OUTPUT AUXOUT AUXIN +5V -2.5VA +3VA



Board: 4 copper layers, 78 parts (26 on the bottom side), 59 nets.

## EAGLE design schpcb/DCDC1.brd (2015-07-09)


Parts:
C1: 100pF; 0603
C2, C3: 47pF; 0603
C4, C5: 100n; 0603
C6, C7, C11: 100nF; 0603
C8, C9, C10, C12: 100µF; CT6032
D1, D2, D3, D4, D5, D6: SK14; DO214AC
IC1: 74HC00D; SO14
IC2: 74HCT132D; SO14
Q1, Q2: BSS123; SOT23
R1, R2: 10k; 0603
R3, R4: 1.54k; 0603
R5, R6: 150; 0603
T1: EFD15DCDCPM5P33EFD15; B66414-W1008-D1

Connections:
+3.6V: C11.1, C12.+, D5.C, D6.C
+5.5V: C7.1, C8.+, D1.C, D2.C
-5.5V: C6.2, C9.-, D3.A, D4.A
GND: C6.1, C7.2, C8.-, C9.+, C11.2, C12.-, T1.4 (SM)
GNDIO: C2.1, C3.1, C4.1, C5.1, C10.-, IC1.7 (GND), IC2.7 (GND), Q1.2 (S), Q2.2 (S)
unnamed: IC2.1 (I0), IC2.2 (I1), R1.1
unnamed: IC1.4 (I0), IC1.5 (I1), IC2.3 (O)
unnamed: C1.1, R1.2, R2.1
unnamed: C1.2, IC1.1 (I0), IC1.2 (I1), IC1.6 (O)
unnamed: IC1.3 (O), IC2.4 (I0), IC2.5 (I1), IC2.12 (I0), R2.2, R4.1
unnamed: IC1.12 (I0), IC1.13 (I1), IC2.11 (O)
unnamed: C2.2, IC2.13 (I1), R4.2
unnamed: IC2.6 (O), IC2.9 (I0), R3.1
unnamed: C3.2, IC2.10 (I1), R3.2
unnamed: IC1.9 (I0), IC1.10 (I1), IC2.8 (O)
unnamed: IC1.11 (O), R5.1
unnamed: IC1.8 (O), R6.1
unnamed: Q2.1 (G), R6.2
unnamed: D5.A, T1.5 (S2P)
unnamed: Q1.1 (G), R5.2
unnamed: Q1.3 (D), T1.1 (P1P)
unnamed: D1.A, D4.C, T1.7 (S1N)
unnamed: D2.A, D3.C, T1.8 (S1P)
unnamed: Q2.3 (D), T1.3 (P1N)
unnamed: D6.A, T1.6 (S2N)
VCCIO: C4.2, C5.2, C10.+, IC1.14 (VCC), IC2.14 (VCC), T1.2 (P1M)



Board: 2 copper layers, 31.1 x 29.1 mm, 29 parts (20 on the bottom side), 26 nets.

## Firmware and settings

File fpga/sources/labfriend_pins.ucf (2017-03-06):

##Constraints File For Super Scope Pro#####
##By: Trond Egil Gran #####################
##Date:11/08 2013#########################


###### PIN CONFIUGURATIONS ################

###### I2S Pin Config ####################
# I2SSCLK
NET "I2SSCLK" LOC = P16;
NET "I2SSCLK" IOSTANDARD = LVCMOS33;
NET "I2SSCLK" OUT_TERM = UNTUNED_50;
#I2SDATAIN
NET "I2SDATAIN" LOC = M16;
NET "I2SDATAIN" IOSTANDARD = LVCMOS33;
NET "I2SDATAOUT" OUT_TERM = UNTUNED_50;
#I2SDATAOUT
NET "I2SDATAOUT" LOC = N14;
NET "I2SDATAOUT" IOSTANDARD = LVCMOS33;
#I2SBCK
NET "I2SBCK" LOC = N16;
NET "I2SBCK" IOSTANDARD = LVCMOS33;
NET "I2SBCK" OUT_TERM = UNTUNED_50;
#I2SLRCK
NET "I2SLRCK" LOC = P15;
NET "I2SLRCK" IOSTANDARD = LVCMOS33;
NET "I2SLRCK" OUT_TERM = UNTUNED_50;

##### MasterClock #######################
# MSTCLK
NET "MSTCLK" LOC = B10;
NET "MSTCLK" IOSTANDARD = LVCMOS33;

#### GPSPI/ SCOPE SPI CONNECTION ########
# GPSPICLK
NET "GPSPICLK" LOC = A13;
NET "GPSPICLK" IOSTANDARD = LVCMOS33;
# GPSPIDATA
NET "GPSPIDATA" LOC = A14;
NET "GPSPIDATA" IOSTANDARD = LVCMOS33;
# GPSPICS
NET "GPSPICS" LOC = B14;
NET "GPSPICS" IOSTANDARD = LVCMOS33;

##### USB CONNECTION/ FT232H ############
# USBSK
NET "USBSK" LOC = B8;
NET "USBSK" IOSTANDARD = LVCMOS33;
NET "USBSK" CLOCK_DEDICATED_ROUTE = FALSE;
# USBDI
NET "USBDI" LOC = A7;
NET "USBDI" IOSTANDARD = LVCMOS33;
#NET "USBDI" OUT_TERM = UNTUNED_50;
# USBDO
NET "USBDO" LOC = A9;
NET "USBDO" IOSTANDARD = LVCMOS33;
# USBCS
NET "USBCS" LOC = C9;
NET "USBCS" IOSTANDARD = LVCMOS33;
# USBGPIO0
NET "USBGPIO0" LOC = A8;
NET "USBGPIO0" IOSTANDARD = LVCMOS33;
# USBGPIO1
NET "USBGPIO1" LOC = A10;
NET "USBGPIO1" IOSTANDARD = LVCMOS33;


NET "USBSK" TNM_NET = "tnm_usbsk";
NET "USBDI" TNM_NET = "tnm_usbo";
TIMESPEC "TS_usbsk" = PERIOD "tnm_usbsk" 33.33 ns;
#according to ft232h datasheet the hold time should be 16.67-11=5.67ns
#substracting pcb delay of 413ps gives 5.257nS
TIMESPEC "TS_USBO" = FROM "tnm_usbsk" TO "tnm_usbo" 6 ns;

######### PWM outputs ########################
#
NET "PWMOFFS0" LOC = C10;
NET "PWMOFFS0" IOSTANDARD = LVCMOS33;
NET "PWMOFFS1" LOC = C11;
NET "PWMOFFS1" IOSTANDARD = LVCMOS33;
NET "PWMEXVO" LOC = D11;
NET "PWMEXVO" IOSTANDARD = LVCMOS33;
NET "PWMLAVIO" LOC = D12;
NET "PWMLAVIO" IOSTANDARD = LVCMOS33;
NET "PWMLA" LOC = E12;
NET "PWMLA" IOSTANDARD = LVCMOS33;
NET "LADVREF" LOC = N6;
NET "LADVREF" IOSTANDARD = LVCMOS33;

### FLASH Memory ########################
# FLASHDIN
#NET "FLASHDIN" LOC = P65;
#NET "FLASHDIN" IOSTANDARD = LVCMOS33;
# FLASHMOSI
#NET "FLASHMOSI" LOC = P64;
#NET "FLASHMOSI" IOSTANDARD = LVCMOS33;
# FLASHCCLK
#NET "FLASHCCLK" LOC = P70;
#NET "FLASHCCLK" IOSTANDARD = LVCMOS33;
# FLASHCSO_B
#NET "FLASHCSO_B" LOC = P38;
#NET "FLASHCSO_B" IOSTANDARD = LVCMOS33;

#### ANALG SELECT #####################
# Select commponent Measurement or Audio
NET "CMP_MEAS_SEL" LOC = R16;
NET "CMP_MEAS_SEL" IOSTANDARD = LVCMOS33;
# Component measure range
NET "CMPMEAS_EN" LOC = N12;
NET "CMPMEAS_EN" IOSTANDARD = LVCMOS33;
NET "CMPMEAS_A" LOC = R12;
NET "CMPMEAS_A" IOSTANDARD = LVCMOS33;
NET "CMPMEAS_B" LOC = M13;
NET "CMPMEAS_B" IOSTANDARD = LVCMOS33;

### Digital IO + 1 CH AWG #############
# LAD07
NET "LAD07[*]" IOSTANDARD = SSTL3_I;
NET "LAD07[0]" LOC = T9;
NET "LAD07[1]" LOC = P7;
NET "LAD07[2]" LOC = T8;
NET "LAD07[3]" LOC = T7;
NET "LAD07[4]" LOC = R7;
NET "LAD07[5]" LOC = T6;
NET "LAD07[6]" LOC = R5;
NET "LAD07[7]" LOC = T4;

# LAD815
NET "LAD815[*]" IOSTANDARD = LVCMOS33;
NET "LAD815[*]" OUT_TERM = UNTUNED_50;
NET "LAD815[0]" LOC = N5;
NET "LAD815[1]" LOC = P5;
NET "LAD815[2]" LOC = P6;
NET "LAD815[3]" LOC = N8;
NET "LAD815[4]" LOC = N9;
NET "LAD815[5]" LOC = P9;
NET "LAD815[6]" LOC = N11;
NET "LAD815[7]" LOC = P12;


##### Scope ADC COnenctions ################
# ADA
NET "ADA[0]" LOC = E16;
NET "ADA[0]" IOSTANDARD = LVCMOS33;
NET "ADA[1]" LOC = E15;
NET "ADA[1]" IOSTANDARD = LVCMOS33;
NET "ADA[2]" LOC = D16;
NET "ADA[2]" IOSTANDARD = LVCMOS33;
NET "ADA[3]" LOC = D14;
NET "ADA[3]" IOSTANDARD = LVCMOS33;
NET "ADA[4]" LOC = C16;
NET "ADA[4]" IOSTANDARD = LVCMOS33;
NET "ADA[5]" LOC = C15;
NET "ADA[5]" IOSTANDARD = LVCMOS33;
NET "ADA[6]" LOC = B16;
NET "ADA[6]" IOSTANDARD = LVCMOS33;
NET "ADA[7]" LOC = B15;
NET "ADA[7]" IOSTANDARD = LVCMOS33;
NET "ADAC" LOC = F15;
NET "ADAC" IOSTANDARD = LVCMOS33;
NET "ADAC" OUT_TERM = UNTUNED_50;
NET "ADAP" LOC = F16;
NET "ADAP" IOSTANDARD = LVCMOS33;
# ADB
NET "ADB[0]" LOC = K14;
NET "ADB[0]" IOSTANDARD = LVCMOS33;
NET "ADB[1]" LOC = K16;
NET "ADB[1]" IOSTANDARD = LVCMOS33;
NET "ADB[2]" LOC = K15;
NET "ADB[2]" IOSTANDARD = LVCMOS33;
NET "ADB[3]" LOC = J16;
NET "ADB[3]" IOSTANDARD = LVCMOS33;
NET "ADB[4]" LOC = H16;
NET "ADB[4]" IOSTANDARD = LVCMOS33;
NET "ADB[5]" LOC = H15;
NET "ADB[5]" IOSTANDARD = LVCMOS33;
NET "ADB[6]" LOC = G16;
NET "ADB[6]" IOSTANDARD = LVCMOS33;
NET "ADB[7]" LOC = F14;
NET "ADB[7]" IOSTANDARD = LVCMOS33;
NET "ADBC" LOC = L16;
NET "ADBC" IOSTANDARD = LVCMOS33;
NET "ADBC" OUT_TERM = UNTUNED_50;

##### HF DAC Connections #######################
##
NET "HFDAC_DI" LOC = L13;
NET "HFDAC_DI" IOSTANDARD = LVCMOS33;
NET "HFDAC_DI" OUT_TERM = UNTUNED_50;
NET "HFDAC_CS" LOC = J13;
NET "HFDAC_CS" IOSTANDARD = LVCMOS33;
NET "HFDAC_CS" OUT_TERM = UNTUNED_50;
NET "HFDAC_CLK" LOC = F13;
NET "HFDAC_CLK" IOSTANDARD = LVCMOS33;
NET "HFDAC_CLK" OUT_TERM = UNTUNED_50;
#NET "HFDAC_CLK" CLOCK_DEDICATED_ROUTE = FALSE;

#### LF Control SPI ##################################
# Audio CODEC and DC ADC SPI 
NET "AU_CSN" LOC = T13;
NET "AU_CSN" IOSTANDARD = LVCMOS33;
NET "AU_CSN" OUT_TERM = UNTUNED_50;
NET "AU_CCLK" LOC = T14;
NET "AU_CCLK" IOSTANDARD = LVCMOS33;
NET "AU_CCLK" OUT_TERM = UNTUNED_50;
NET "AU_CDTI" LOC = T15;
NET "AU_CDTI" IOSTANDARD = LVCMOS33;
NET "AU_CDTI" OUT_TERM = UNTUNED_50;
NET "DC_DOUT" LOC = T12;
NET "DC_DOUT" IOSTANDARD = LVCMOS33;
NET "DC_CS" LOC = M14;
NET "DC_CS" IOSTANDARD = LVCMOS33;
NET "DC_CS" OUT_TERM = UNTUNED_50;
# Audio Control
NET "AUPDN" LOC = R15;
NET "AUPDN" IOSTANDARD = LVCMOS33;
NET "AUPDN" OUT_TERM = UNTUNED_50;
NET "AU_OVFR" LOC = M15;
NET "AU_OVFR" IOSTANDARD = LVCMOS33;
NET "AU_OVFL" LOC = R14;
NET "AU_OVFL" IOSTANDARD = LVCMOS33;

############################################################################
# VCC AUX VOLTAGE 
############################################################################
CONFIG VCCAUX=3.3; # Valid values are 2.5 and 3.3

############################################################################
## I/O TERMINATION                                                          
############################################################################
NET "mcb3_dram_dq[*]"                                 IN_TERM = UNTUNED_SPLIT_50;
NET "mcb3_dram_dqs"                                   IN_TERM = UNTUNED_SPLIT_50;
NET "mcb3_dram_dqs_n"                                 IN_TERM = UNTUNED_SPLIT_50;
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

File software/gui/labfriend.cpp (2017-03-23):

#include <stdio.h>
#include <stdlib.h>
#include <QApplication>
#include <time.h>
#include <stdint.h>
#define _ISOC9X_SOURCE  1
#define _ISOC99_SOURCE  1
#include  <math.h>




#include <QFileDialog>
#include <QString>
#include <QTimer>
#include <QTextStream>
#include <QDateTime>


#include "labfriend.h"
extern "C"
{
    #include <audio_codec.h>
    #include <scope_control.h>
    #include <dcio.h>
    #include <spicomm.h>
    #include <sys/time.h>
    #include <time.h>
    #include <unistd.h>
}





void labfriend::open_DO_file(void)
{
  
    uint8_t dobit0;
    uint8_t dobit1;
    uint8_t dobit2;
    uint8_t dobit3;
    uint8_t dobit4;
    uint8_t dobit5;
    uint8_t dobit6;
    uint8_t dobit7;

    QString fileName = QFileDialog::getOpenFileName(this);
    
     QFile file(fileName);
     if (file.open(QFile::ReadOnly)) 
     {

        char buf[1024];
        qint64 lineLength;
        char * pEnd;
        int i=0;


        printf("startfile \n");
        while( !file.atEnd() )
        {
            lineLength = file.readLine(buf, sizeof(buf));

            if (lineLength != -1)
            {
            // the line is available in buf
              dobit0 = strtod (buf, &pEnd);
              dobit1 = strtod (pEnd, &pEnd);
              dobit2 = strtod (pEnd, &pEnd);
              dobit3 = strtod (pEnd, &pEnd);
              dobit4 = strtod (pEnd, &pEnd);
              dobit5 = strtod (pEnd, &pEnd);
              dobit6 = strtod (pEnd, &pEnd);
              dobit7 = strtod (pEnd, NULL);
              dobit07[i] = dobit0 | (dobit1 << 1) | (dobit2 << 2) | (dobit3 << 3) | (dobit4 << 4) | (dobit5 << 5) | (dobit6 << 6) | (dobit7 << 7);
              printf("byte %d is %x\n", i, dobit07[i]);
              i++;

            }

        }
        printf("i is %d \n", i);
        dosize = i;
    }
	
}

void labfriend::open_AO_file(void)
{

   double temp_values;

    QString fileName = QFileDialog::getOpenFileName(this);

     QFile file(fileName);
     if (file.open(QFile::ReadOnly))
     {

        char buf[1024];
        qint64 lineLength;
        int i=0;


        printf("startfile \n");
        while( !file.atEnd() )
        {
            lineLength = file.readLine(buf, sizeof(buf));

            if (lineLength != -1)
            {
            // the line is available in buf
              temp_values = strtod (buf, NULL);
              aovalue[i] = (uint8_t)round(temp_values*RFDACMAX/RFDACREF);
              printf("byte %d is %f %d\n", i, temp_values, aovalue[i]);
              i++;

            }

        }
        printf("i is %d \n", i);
        aosize = i;
    }

}







void labfriend::ScopeRun(void)
{

   superplot.timerA->stop();
   {
        if(dataLoggerEnabled)
        {
            if( dataLoggerTimer < dataLoggerTimerMax )
            {
                dataLoggerTimer++;
            }
            else
            {
                getLoggerData();
                //Run data logger funcget
                dataLoggerTimer = 0;
            }
        }

        if(scopeEnabled)
        {
            if( scopeUpdateTimer < scopeUpdateTimerMax )
            {
                scopeUpdateTimer++;
            }
            else
            {
                scope_run_main();
                //run scope data
                scopeUpdateTimer = 0;
            }

        }

        if(audioEnabled)
        {
            if( audioUpdateTimer < audioUpdateTimerMax )
            {
                audioUpdateTimer++;
            }
            else
            {
                if(audioRepeat || audio_single_trig)
                {
                    get_audio_data();
                    if (audioRecFinished == true)  audio_single_trig = 0;
                }
                audioUpdateTimer = 0;
            }
        }

        audio_generate();

    }
   superplot.timerA->start();
}


void labfriend::singleScopeRun(bool checked)
{
    scopeSingle = checked;
    printf("yes dude %d\n", checked);
}



void labfriend::setVoltDivADC1(QString qsSource)
{
    setVoltDiv(adc_channel_0, qsSource);
}

void labfriend::setVoltDivADC2(QString qsSource)
{
    setVoltDiv(adc_channel_1, qsSource);
}

void labfriend::setAcADC1(bool checked)
{
    if(checked)
    {
        set_ACDC(adc_channel_0, AC);
    }
    else
    {
        set_ACDC(adc_channel_0, DC);
    }
}

void labfriend::setAcADC2(bool checked)
{
    if(checked)
    {
        set_ACDC(adc_channel_1, AC);
    }
    else
    {
        set_ACDC(adc_channel_1, DC);
    }
}

void labfriend::GenerateAudio(bool checked)
{
    GenerateAudioEnable = checked;
}



void labfriend::dataLoggerChekerbox(bool checked)
{
    dataLoggerEnabled = checked;
}

void labfriend::dataLoggerFileChekerbox(bool checked)
{
    dataLoggertoFile = checked;
}


void labfriend::setDigiOut0(bool checked)
{
    if(checked)
    {
        digitalOutputByte = digitalOutputByte | 0x01;
    }
    else
    {
        digitalOutputByte = digitalOutputByte & ~0x01;
    }
}
void labfriend::setDigiOut1(bool checked)
{
    if(checked)
    {
        digitalOutputByte = digitalOutputByte | 0x02;
    }
    else
    {
        digitalOutputByte = digitalOutputByte & ~0x02;
    }
}
void labfriend::setDigiOut2(bool checked)
{
    if(checked)
    {
        digitalOutputByte = digitalOutputByte | 0x04;
    }
    else
    {
        digitalOutputByte = digitalOutputByte & ~0x04;
    }
}
void labfriend::setDigiOut3(bool checked)
{
    if(checked)
    {
        digitalOutputByte = digitalOutputByte | 0x08;
    }
    else
    {
        digitalOutputByte = digitalOutputByte & ~0x08;
    }
}
void labfriend::setDigiOut4(bool checked)
{
    if(checked)
    {
        digitalOutputByte = digitalOutputByte | 0x10;
    }
    else
    {
        digitalOutputByte = digitalOutputByte & ~0x10;
    }
}
void labfriend::setDigiOut5(bool checked)
{
    if(checked)
    {
        digitalOutputByte = digitalOutputByte | 0x20;
    }
    else
    {
        digitalOutputByte = digitalOutputByte & ~0x20;
    }
}
void labfriend::setDigiOut6(bool checked)
{
    if(checked)
    {
        digitalOutputByte = digitalOutputByte | 0x40;
    }
    else
    {
        digitalOutputByte = digitalOutputByte & ~0x40;
    }
}
void labfriend::setDigiOut7(bool checked)
{
    if(checked)
    {
        digitalOutputByte = digitalOutputByte | 0x80;
    }
    else
    {
        digitalOutputByte = digitalOutputByte & ~0x80;
    }
}

void labfriend::setFileDOenable(bool checked)
{
    doFileEnable = checked;
    dobyteCounter = 0;
}

void labfriend::setFileLoop(bool checked)
{
    doLoopFile = checked;
}


void labfriend::setTrigType(QString qsTrigType)
{
    if( !qsTrigType.compare("Pos Edge") )
    {
        triggerType = trigger_edge_pos;
    }
    else if( !qsTrigType.compare("Neg Edge") )
    {
        triggerType = trigger_edge_neg;
    }
    else if( !qsTrigType.compare("Automatic") )
    {
        triggerType = trigger_automatic;
    }
}

void labfriend::setLoggerGain1(QString qsTrigType)
{
    if( !qsTrigType.compare("X1") )
    {
        loggerGainCH1 = LOGGERGAIN1;
    }
    else if( !qsTrigType.compare("X2") )
    {
        loggerGainCH1 = LOGGERGAIN2;
    }
    else if( !qsTrigType.compare("X4") )
    {
        loggerGainCH1 = LOGGERGAIN4;
    }
    else if( !qsTrigType.compare("X8") )
    {
        loggerGainCH1 = LOGGERGAIN8;
    }

}

void labfriend::setLoggerGain2(QString qsTrigType)
{
    if( !qsTrigType.compare("X1") )
    {
        loggerGainCH2 = LOGGERGAIN1;
    }
    else if( !qsTrigType.compare("X2") )
    {
        loggerGainCH2 = LOGGERGAIN2;
    }
    else if( !qsTrigType.compare("X4") )
    {
        loggerGainCH2 = LOGGERGAIN4;
    }
    else if( !qsTrigType.compare("X8") )
    {
        loggerGainCH2 = LOGGERGAIN8;
    }

}

void labfriend::setLoggerGain3(QString qsTrigType)
{
    if( !qsTrigType.compare("X1") )
    {
        loggerGainCH3 = LOGGERGAIN1;
    }
    else if( !qsTrigType.compare("X2") )
    {
        loggerGainCH3 = LOGGERGAIN2;
    }
    else if( !qsTrigType.compare("X4") )
    {
        loggerGainCH3 = LOGGERGAIN4;
    }
    else if( !qsTrigType.compare("X8") )
    {
        loggerGainCH3 = LOGGERGAIN8;
    }

}

void labfriend::getLoggerData( void )
{
    QFile file("datalogger.txt");
    loggerChannel1.resize(loggersample+1);
    loggerChannel2.resize(loggersample+1);
    loggerChannel3.resize(loggersample+1);
    loggerExvo.resize(loggersample+1);
    loggerTemp.resize(loggersample+1);
    printf("lgain %x %x %x", loggerGainCH1, loggerGainCH2, loggerGainCH3);
    loggerChannel1[loggersample]  = getVoltage(LOGGERADC0 | SINGLECONVERSION | LOGGERSPS15 | loggerGainCH1);
    loggerChannel2[loggersample]  = getVoltage(LOGGERADC1 | SINGLECONVERSION | LOGGERSPS15 | loggerGainCH2);
    loggerChannel3[loggersample]  = getVoltage(LOGGERADC2 | SINGLECONVERSION | LOGGERSPS15 | loggerGainCH3);
    loggerExvo[loggersample]      = getVoltage(LOGGERADC3 | SINGLECONVERSION | LOGGERSPS15 | LOGGERGAIN1);
    loggerTemp[loggersample]      = getVoltage(LOGGERTEMP | SINGLECONVERSION | LOGGERSPS15 | LOGGERGAIN1);
    Logxaxis.resize(loggersample + 1);
    Logxaxis[loggersample] = loggersample;
    superplot.ui.qcpDataLog->graph(0)->setData(Logxaxis, loggerChannel1);
    superplot.ui.qcpDataLog->graph(1)->setData(Logxaxis, loggerChannel2);
    superplot.ui.qcpDataLog->graph(2)->setData(Logxaxis, loggerChannel3);
    superplot.ui.qcpDataLog->graph(3)->setData(Logxaxis, loggerTemp);

    superplot.ui.lcdCh1->display(loggerChannel1[loggersample] * 1000);
    superplot.ui.lcdCh2->display(loggerChannel2[loggersample] * 1000);
    superplot.ui.lcdCh3->display(loggerChannel3[loggersample] * 1000);
    superplot.ui.lcdEXVO->display(loggerExvo[loggersample] * 1000 );
    superplot.ui.lcdTemp->display(loggerTemp[loggersample] );

    superplot.ui.qcpDataLog->xAxis->setRange(0, loggersample);
    emit replotTriggerDataNow();

    if( dataLoggertoFile == true)
    {
        file.open(QIODevice::WriteOnly | QIODevice::Text | QIODevice::Append);
        QTextStream out(&file);
        out << QDateTime::currentMSecsSinceEpoch() << " " << loggerChannel1[loggersample] << " " << loggerChannel2[loggersample] << " "
            << loggerChannel3[loggersample] << " " << loggerExvo[loggersample] << " " << loggerTemp[loggersample] << endl;
        file.close();
    }

    if( loggersample < LOGGERMAXSIZE)
    {
        loggersample++;
    }
    else
    {
        loggersample = 0;
    }

}



void labfriend::setTrigSource(QString qsSource)
{
    if( !qsSource.compare("Trace 1") )
    {
        triggerSource = 0;
    }
    else if( !qsSource.compare("Trace 2") )
    {
        triggerSource = 1;
    }
    else if( !qsSource.compare("Trace 3") )
    {
        triggerSource = 2;
    }
    else if( !qsSource.compare("Trace 4") )
    {
        triggerSource = 3;
    }
    triggerValue = set_trigger_voltage(triggerSource, superplot.ui.dbsTriggerLevel->value()/1000);
}



void labfriend::setOffsetADC1(double offsetVoltage)
{
    double attenuator = 1;
    if (scopeVdiv[0] > 201e-3)
    {
        attenuator = 10;
    }
    scopeOffset[0] = offsetVoltage;
    setVoltage(HSADCOFFSET0, scopeOffset[0]/(attenuator*1000.0), ScopeOffsetGainError[0], ADCOffsetError[0]/1000.0);
}

void labfriend::setOffsetADC2(double offsetVoltage)
{
    double attenuator  = 1;
    if (scopeVdiv[1] > 201e-3)
    {
        attenuator = 10;
    }
    scopeOffset[1] = offsetVoltage;
    setVoltage(HSADCOFFSET1, scopeOffset[1]/(attenuator*1000.0), ScopeOffsetGainError[1], ADCOffsetError[1]/1000.0);
}

void labfriend::setOffsetTime(double offsetTime)
{

    scopeOffsetTime = offsetTime;
}

void labfriend::setEXvoltage(double tempvalue)
{
    EXvoltage = tempvalue;
}

void labfriend::setIOvoltage(double tempvalue)
{
    digitalIOvoltage = tempvalue;
}

void labfriend::setdIrefVoltage(double tempvalue)
{
    digitalIrefVoltage = tempvalue;
}

void labfriend::setdIoffsetVoltage(double tempvalue)
{
    digitalIoffsetVoltage = tempvalue;
}


void labfriend::IOvoltageButton( void )
{
    setVoltage( LAVIO , digitalIOvoltage, LAVIOOffsetGainError, LAVIOOffsetOffsetError);
}


void labfriend::DinVrefVoltageButton( void )
{
    setVoltage( LADVREF , digitalIrefVoltage, LAVIrefOffsetGainError, LAVIrefOffsetOffsetError);
}


void labfriend::DinOffsetVoltageButton( void )
{
    setVoltage( LAOFFSET , digitalIoffsetVoltage, LAVIoffsetGainError, LAVIoffsetOffsetError);
}

void labfriend::EXvoltageButton( void )
{
    setVoltage( EXVO , EXvoltage, EXVOOffsetGainError, EXVOOffsetOffsetError);
}


void labfriend::setTriggerValue(double dbTrigger)
{
    triggerValue = set_trigger_voltage(triggerSource, dbTrigger/1000);
}


void labfriend::ManageCursor(QCustomPlot *customPlot, QCPCursor *cursor, double x, double y, QPen pen)
{
    if(cursorEnabled)
    {
        if(cursor->hLine) customPlot->removeItem(cursor->hLine);
        cursor->hLine = new QCPItemLine(customPlot);
       // customPlot->addItem(cursor->hLine);
        cursor->hLine->setPen(pen);
        cursor->hLine->start->setCoords(QCPRange::minRange, y);
        cursor->hLine->end->setCoords(QCPRange::maxRange, y);

        if(cursor->vLine) customPlot->removeItem(cursor->vLine);
        cursor->vLine = new QCPItemLine(customPlot);
        //customPlot->addItem(cursor->vLine);
        cursor->vLine->setPen(pen);
        cursor->vLine->start->setCoords( x, -QCPRange::maxRange);
        cursor->vLine->end->setCoords( x, QCPRange::maxRange);
    }
}

void labfriend::mouseRelease(QMouseEvent* event)
{
    static QCPCursor cursor1, cursor2;
    double x=superplot.ui.qcpScopeDisplay->xAxis->pixelToCoord(event->pos().x());
    double y=superplot.ui.qcpScopeDisplay->yAxis->pixelToCoord(event->pos().y());
    double cursorXdiff, cursorYdiff, frequ;
    if(event->button() == Qt::LeftButton)
    {
        ManageCursor(superplot.ui.qcpScopeDisplay, &cursor1, x, y, QPen(Qt::black));
        superplot.ui.lbXcursor1->setText(QString::number(x, 'e', 3) + QString("s") ) ;
        superplot.ui.lbYcursor1->setNum(y);
        xCursor1Point = x;
        yCursor1Point = y;
    }
    else if(event->button() == Qt::RightButton)
    {
        ManageCursor(superplot.ui.qcpScopeDisplay, &cursor2, x, y, QPen(Qt::gray));
        superplot.ui.lbXcursor2->setText(QString::number(x, 'e', 3) + QString("s") );
        superplot.ui.lbYcursor2->setNum(y);
        xCursor2Point = x;
        yCursor2Point = y;
    }
    else if(event->button() == Qt::MiddleButton)
    {
        if(zoomYaxis == true)
        {
            zoomYaxis = false;
            superplot.ui.qcpScopeDisplay->axisRect()->setRangeZoom(Qt::Vertical);
        }
        else
        {
            zoomYaxis = true;
            superplot.ui.qcpScopeDisplay->axisRect()->setRangeZoom(Qt::Horizontal);
        }

    }
    cursorXdiff = xCursor2Point - xCursor1Point;
    cursorYdiff = yCursor2Point - yCursor1Point;
    frequ = 1.0/cursorXdiff;
    superplot.ui.lbTimeDiff->setText(QString::number(cursorXdiff, 'e', 3) + QString("s") );
    superplot.ui.lbFrequency_2->setText(QString::number(frequ, 'e', 3) + QString("Hz") );
    superplot.ui.lbVoltageDiffCh1->setText(QString::number(cursorYdiff*scopeVdiv[0], 'e', 3) + QString("V") );
    superplot.ui.lbVoltageDiffCh2->setText(QString::number(cursorYdiff*scopeVdiv[1], 'e', 3) + QString("V") );
    superplot.ui.qcpScopeDisplay->replot();
    cursorEnabled=true;
}

void labfriend::mouseReleaseAudio(QMouseEvent* event)
{
    static QCPCursor cursor1, cursor2;
    double x=superplot.ui.qcpAudioDisplay->xAxis->pixelToCoord(event->pos().x());
    double y=superplot.ui.qcpAudioDisplay->yAxis->pixelToCoord(event->pos().y());
    double cursorXdiff, cursorYdiff, frequ;
    if(event->button() == Qt::LeftButton)
    {
        ManageCursor(superplot.ui.qcpAudioDisplay, &cursor1, x, y, QPen(Qt::black));
        superplot.ui.lbAudioCursorX1->setText(QString::number(x, 'e', 3) + QString("s") ) ;
        superplot.ui.lbAudioCursorY1->setNum(y);
        xCursor1Point = x;
        yCursor1Point = y;
    }
    else if(event->button() == Qt::RightButton)
    {
        ManageCursor(superplot.ui.qcpAudioDisplay, &cursor2, x, y, QPen(Qt::gray));
        superplot.ui.lbAudioCursorX2->setText(QString::number(x, 'e', 3) + QString("s") );
        superplot.ui.lbAudioCursorY2->setNum(y);
        xCursor2Point = x;
        yCursor2Point = y;
    }
    else if(event->button() == Qt::MiddleButton)
    {
        if(zoomYaxisAudio == true)
        {
            zoomYaxisAudio = false;
            superplot.ui.qcpAudioDisplay->axisRect()->setRangeZoom(Qt::Vertical);
        }
        else
        {
            zoomYaxisAudio   = true;
            superplot.ui.qcpAudioDisplay->axisRect()->setRangeZoom(Qt::Horizontal);
        }

    }
    cursorXdiff = xCursor2Point - xCursor1Point;
    cursorYdiff = yCursor2Point - yCursor1Point;
    frequ = 1.0/cursorXdiff;
    superplot.ui.lbAudioCursorDiffTime->setText(QString::number(cursorXdiff, 'e', 3) + QString("s") );
    superplot.ui.lbAudioCursorDiffFreq->setText(QString::number(frequ, 'e', 3) + QString("Hz") );
    superplot.ui.lbAudioCursorYDiffVoltage->setText(QString::number(cursorYdiff*scopeVdiv[0], 'e', 3) + QString("V") );
    superplot.ui.qcpAudioDisplay->replot();
    cursorEnabled=true;
}



void labfriend::setLoggerRate(double loggerSampleRate)
{
    dataLoggerRate = loggerSampleRate;
    dataLoggerTimerMax = round(dataLoggerRate/systemTimerRate);
    dataLoggerTimer = 0;
}

void labfriend::setDOrate(double doSampleRate)
{
    doUpdateRate = doSampleRate;
    doUpdateTimerMax = round(doUpdateRate/systemTimerRate);
    doUpdateTimer = 0;
}

void labfriend::setAudioRecTime(double time)
{
    audioRecTime = time;
}

void labfriend::setAudioRecRepeate(bool checked)
{
    audioRepeat = checked;
}


//AWG and DWG functions----------------------------

void labfriend::setDWGrate(int dwgrate)
{
    dwgSampleRate = dwgrate;
    double realSrate=1/((double)dwgrate*(1/MASATERCLKFREQ)+(1/MASATERCLKFREQ));
    superplot.ui.tlDWGrate->setNum(realSrate);
}

void labfriend::setAWGrate(int awgrate)
{
    awgSampleRate = awgrate;
    double realSrate=1/(((double)awgrate*(1/MASATERCLKFREQ)+(1/MASATERCLKFREQ))*8);
    superplot.ui.tlAWGrate->setNum(realSrate);
}

void labfriend::dwgRunButton( void )
{
    uint8_t config;
    if(dwgSingle) config=DWG_CONFIG_SINGLE; else config = DWG_CONFIG_LOOP;
    if(dosize == 0)
    {
        printf("NO DATA !!!!!\n");
        return;
    }
    run_dwg(config, dwgSampleRate, dosize, dobit07 );
}

void labfriend::awgRunButton( void )
{
    uint8_t config;
    if(awgSingle) config=DWG_CONFIG_SINGLE; else config = DWG_CONFIG_LOOP;
    if(aosize == 0)
    {
        printf("NO DATA !!!!!\n");
        return;
    }
    run_awg(config, awgSampleRate, aosize, aovalue );
}

void labfriend::awgLoopFun( bool lopstat)
{
    awgSingle = !lopstat;
    printf("toggled ? %x %x\n", awgSingle, lopstat);
}

void labfriend::dwgLoopFun(bool lopstat)
{
    dwgSingle = !lopstat;
    printf("toggled ? %x %x\n", dwgSingle, lopstat);
}
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
int main(int argc, char *argv[])
{

    int appreturn;
	QApplication app(argc, argv);
	labfriend a;
    float * DACsamleft;
    float * DACsamrigth;
    uint8_t databuffer[3];

    //--------OpenSPI----------
    spiOpen();
    //-------------------------

    spiCommand( READ, 0x02, 3);
    spiRead(databuffer, 3);
    printf("databuffer %x %x %x \n", databuffer[0], databuffer[1], databuffer[2]);


    set_probe_attenuation(0, 1.0);
    set_probe_attenuation(1, 1.0);

    a.setInitialCalibration();


    a.dataLoggerEnabled = true;
    a.scopeEnabled = true;
    a.audioEnabled = false;

    DACsamleft = (float *) malloc( 4096 * sizeof(float) );
    if (DACsamleft==NULL) exit (1);
    DACsamrigth = (float *) malloc( 4096 * sizeof(float) );
    if (DACsamrigth==NULL) exit (1);

	
    //Set up Timer for plot updates
    a.superplot.attachCurves();
    a.superplot.InitOPtions();


    a.scopeConnections();
    a.initScopeRun();

    a.superplot.timerA->start();


    a.superplot.show();
	
	//close_port(a.fd);

    appreturn = app.exec();

    delete a.trace_1_raw;
    delete a.trace_2_raw;
    delete a.trace_3_raw;
    delete a.trace_4_raw;

    //--------Close SPI----------------
    spiClose();
    //---------------------------------
    return appreturn;
}

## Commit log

2015-07-10 Finished first outcast for inputchannel
    [InputChannel.brd, InputChannel.sch]
2015-07-13 added analog switch datasheet
2015-08-07 current state
    [LabFriendMain1.brd, LabFriendMain1.sch]
2015-08-18 Pre release checkin
    [InputChannel.brd, InputChannel.sch, LabFriendMain1.brd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]
2015-08-24 Final oreder prototype
    [LabFriendMain1.brd, NetLengths.ods]
2015-09-24 Started adding chnge comments
    [LabFriendMain1.sch]
2015-09-28 added pwm
2015-09-28 Addew pwm to main
2015-09-28 aded last pwm pin
2015-10-07 Added changes
    [NetLengths.ods]
2015-11-12 added copy of i2c dac from superscope, renamed to dcio, should control pwm + DC ADC
2015-11-16 added spi interface, currently just copy of 74595
2015-11-19 Added spi code to make Audio DAC/ADC work
2015-11-24 transformer design
    [TransformerPushPull.ods]
2015-11-26 "made opening of ftdi device device specific to avoid trying to use other devices"
2016-04-27 Changed to fixed 4x clock for hs adc to get correct clock constraints
    [labfriend_pins.ucf]
2016-09-25 removed many bugs now working with triggering, remaining more updates of fpga code for speed
    [labfriend.cpp, labfriend_pins.ucf]
2017-02-03 added bow drawings
    [backpanel.stl, boxCode.scad, frontpanel.stl]
2017-02-03 added top and bottom
    [botom.stl, top.stl]
2017-02-17 added awg and dwg functions, fixed byte order inside was wrong, four and four bits was in the wrong order
    [labfriend.cpp]
2017-02-19 added adc input registgers to iob
2017-02-24 many improovments and bugfixes and added features
    [LabFriendMain1.brd, LabFriendMain1.sch]
2017-02-24 added calibration and test structure and unfinished file for SN1
2017-03-01 fixed speed issues and improved calibration
    [labfriend.cpp, labfriend_calibration.cpp]
2017-03-06 Fixed scope timeo offset and triggering
    [labfriend.cpp, labfriend_pins.ucf, labfriend_scope_controls.cpp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]
2017-03-08 corrected autorun and added compile parameter for libmpsse
    [labfriend_scope_run.cpp]
2017-03-08 added file for programming spi flash trough xc3sprog
2017-03-09 added micamp
    [audiomeaskit.brd, audiomeaskit.sch]
2017-03-11 audio fixes --not finished
    [labfriend.cpp, mainform.cpp]
2017-03-17 added sync on fpga and fix some things on audiomeaskit
    [audiomeaskit.brd, audiomeaskit.sch]
2017-03-23 added fft impulse response button and set micamp button
2017-04-03 fixed memory errors not detected under centos
    [labfriend_calibration.cpp]
